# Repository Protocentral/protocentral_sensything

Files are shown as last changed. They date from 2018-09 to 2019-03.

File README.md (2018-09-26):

ProtoCentral Sensything
=======================================================

### Support us now on Crowd Supply at: https://www.crowdsupply.com/protocentral/sensything

Sensything is an ESP32-based IoT device that has multiple sensor interfaces to read from and send data from both analog and digital sensors.

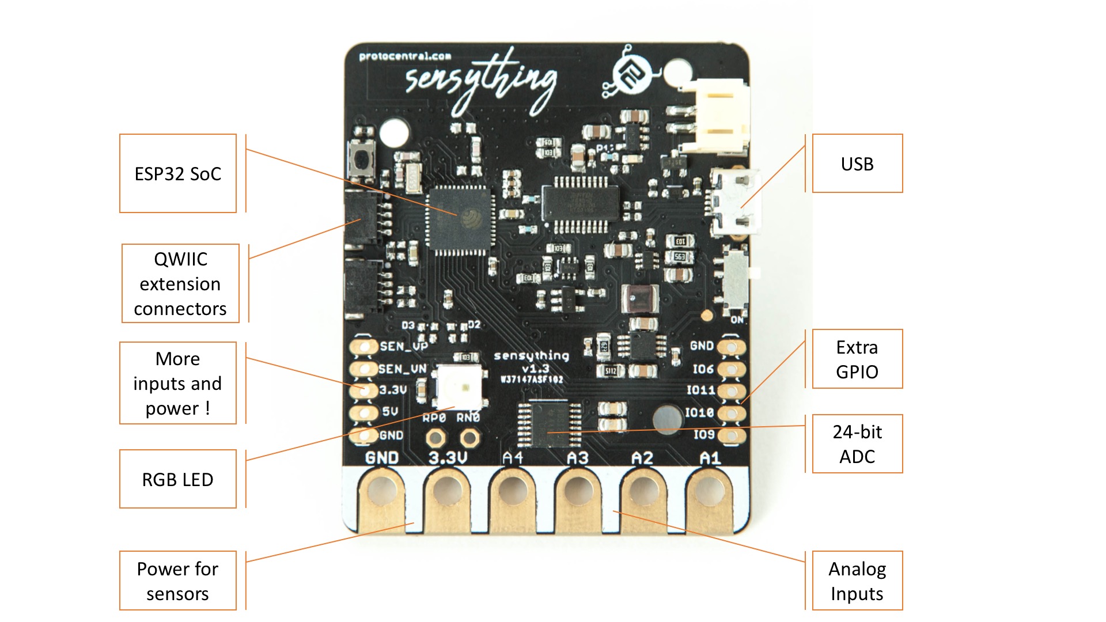
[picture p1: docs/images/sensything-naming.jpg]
HeartyPatch


## Information will be added constantly, keep checking this page for more.

License Information
===================

This product is open source! Both, our hardware and software are open source and licensed under the following licenses:

Hardware
---------

**All hardware is released under [Creative Commons Share-alike 4.0 International](http://creativecommons.org/licenses/by-sa/4.0/).**


You are free to:

* Share — copy and redistribute the material in any medium or format
* Adapt — remix, transform, and build upon the material for any purpose, even commercially.
The licensor cannot revoke these freedoms as long as you follow the license terms.

Under the following terms:

* Attribution — You must give appropriate credit, provide a link to the license, and indicate if changes were made. You may do so in any reasonable manner, but not in any way that suggests the licensor endorses you or your use.
* ShareAlike — If you remix, transform, or build upon the material, you must distribute your contributions under the same license as the original.

Software
--------

**All software is released under the MIT License(http://opensource.org/licenses/MIT).**

THE SOFTWARE IS PROVIDED "AS IS", WITHOUT WARRANTY OF ANY KIND, EXPRESS OR IMPLIED, INCLUDING BUT NOT LIMITED TO THE WARRANTIES OF MERCHANTABILITY, FITNESS FOR A PARTICULAR PURPOSE AND NONINFRINGEMENT. IN NO EVENT SHALL THE AUTHORS OR COPYRIGHT HOLDERS BE LIABLE FOR ANY CLAIM, DAMAGES OR OTHER LIABILITY, WHETHER IN AN ACTION OF CONTRACT, TORT OR OTHERWISE, ARISING FROM, OUT OF OR IN CONNECTION WITH THE SOFTWARE OR THE USE OR OTHER DEALINGS IN THE SOFTWARE.

Please check [*LICENSE.md*](LICENSE.md) for detailed license descriptions.

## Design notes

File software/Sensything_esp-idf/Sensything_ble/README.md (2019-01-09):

# Sensything 
Sensything development repo

**ads1220**

|ADS1220 Pin |Sensything Pin Connection|
|---|---|
| MISO |  19 | 
| MOSI |  23 |
| SCLK |  18 |
| DRDY |  34 |

**QWIIC**

|QWIIC Pin |QWIIC 1 Pin Connection|QWIIC 2 Pin Connection|
|---|---|---|
| SCL |  22 | 25
| SDA |  21 |26

**battery monitor**

ADC ---> 2   
 
```diff
+ Please configure sensything through makemenuconfig
```
* You can enable different channel under makemenuconfig-->sensything configuration-->adc channels
* You can also enable ble, wifi, rgb led through the same sensything configuration
* This code will work with esp-idf release 2.1 and 3.0, please select your idf version from sensything configuration-->select esp-idf version

## BLE DATA FORMAT

#1589F0 ADS1220 #1589F0 

ADS1220 data is send through a proprietary BLE service, it also has a standard [battery service](https://www.bluetooth.com/specifications/gatt/viewer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) to dispaly the battery value.

* data type : float
* service UUID : cd5c 1105 4448 7db8 ae4c d1da8cba36d0
* char UUID :    cd5c 1106 4448 7db8 ae4c d1da8cba36d0
* read voltage in float from ads1220 is multiplied by 100 and converted to int.
* 4byte int data is added to bledata packet, 

  bledatapacket[0] = (uint8_t) ads1220 data  [lsb]
  :
  bledatapacket[3] = (uint8_t) ads1220 data >> 24  [msb]
  
* Ble datapacket[0-3] = channel 1 data
* Ble datapacket[4-7] = channel 2 data
* Ble datapacket[8-11] = channel 3 data
* Ble datapacket[12-15] = channel 4 data

#1589F0 QWIIC #1589F0 

Data from QWIIC sensors is send through another proprietary service

* service UUID : cd5c 1100 4448 7db8 ae4c d1da8cba36d0
* char UUID :    cd5c 1101 4448 7db8 ae4c d1da8cba36d0

It consist of 1byte sensor address and 5 sensor data channels each of 2bytes length
The sensor data length varies based on different sensors

|sensor address |LSB data channel 1| MSB of data channel 1 | ..... |MSB of data channel 5|
|---|---:|---|---|---|
| byte 0 | byte 1 | byte 2 | ........|byte 10 |

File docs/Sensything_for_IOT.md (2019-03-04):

## Sensything as an IOT device

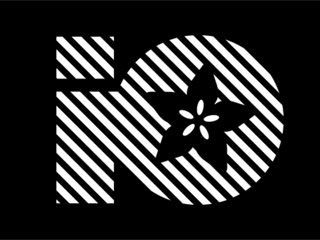
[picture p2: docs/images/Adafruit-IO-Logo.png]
Adafruit-IO-Logo


### * Overview

Sensything along with Adafruit IO is paves way to a whole new world of IOT. It is used for storing and then retrieving data but it can do a lot more than just that!

* Display your sensor (in this case gas sensor data) measuring gas density in real-time, online.
* Make your experiment internet-connected by reading sensor data
* Connect projects to web services like Twitter, RSS feeds, weather services, etc.
* Connect your project to other internet-enabled devices.

### * Sensything Wiring

You will need the following parts for this tutorial but it’s just Plug & Play with Sensything…..!

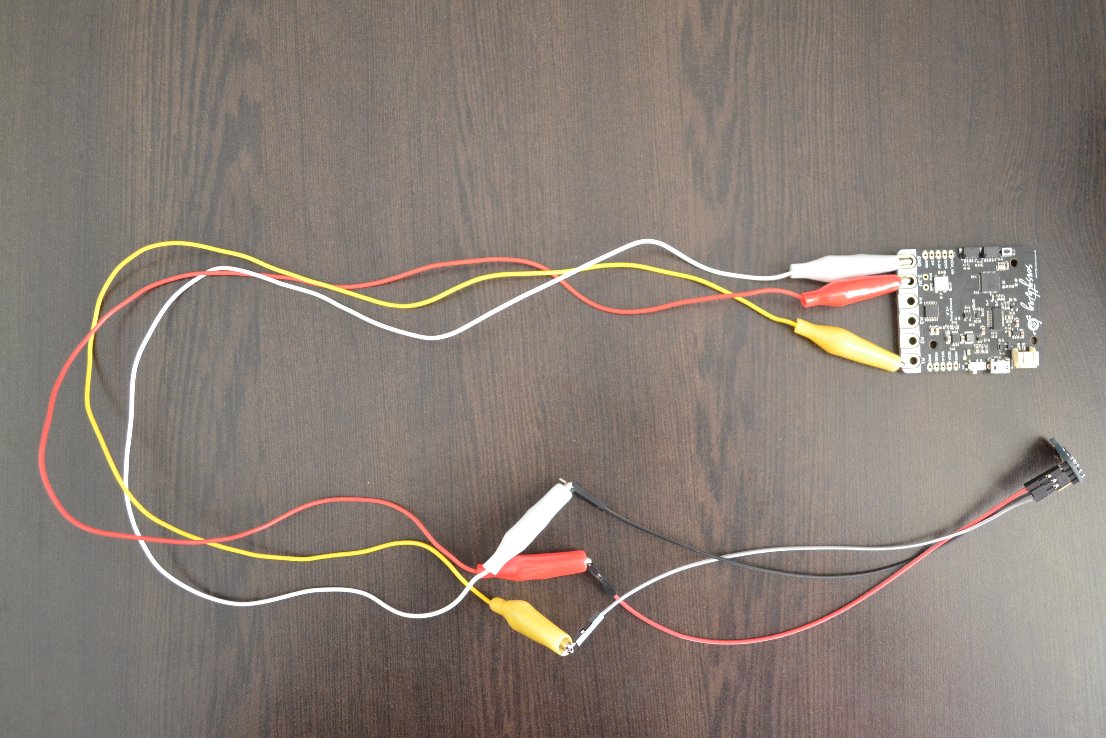
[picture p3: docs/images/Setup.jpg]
Setup


* 1x Sensything Board
* 1x [Mics5524 gas sensor](https://www.adafruit.com/product/3199)
* 3x Alligator Cables
* 3x Jumper wires

Pin connections are as follows:-

* Sensything 3V to Pin 1 of the Mics5524
* Sensything  GND to Pin 2 of the Mics5524
* Sensything  A1 to Pin 3 of the Mics5524 

### * Adafruit IO Setup

The first thing you will need to do is to log in to [Adafruit IO](https://io.adafruit.com/) and visit the Settings page. Click the VIEW AIO KEY button to retrieve your key. A window will pop up with your Adafruit IO Key. 

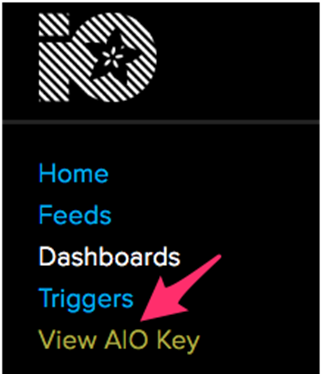
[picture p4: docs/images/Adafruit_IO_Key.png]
Adafruit IO Key
		

### * Creating the Feeds 

First, you will need to create a feed. If you need help getting started with creating feeds on Adafruit IO, check out the [Adafruit IO Feed Basics guide](https://learn.adafruit.com/adafruit-io-basics-feeds/overview).

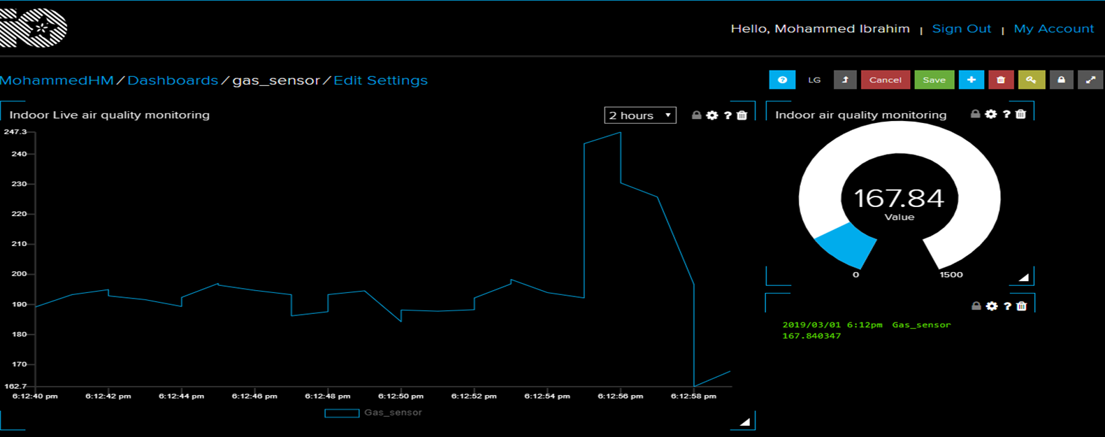
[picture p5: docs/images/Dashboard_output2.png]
Adafruit Dashboard Output2


### * Arduino Setup
 
#### * Install the Required Libraries

Initially you need to install the Adafruit IO, Adafruit MQTT, and Arduino Http Client libraries using the Arduino Library Manager. Navigate to the Manage Libraries... option in the Sketch -> Include Library menu.

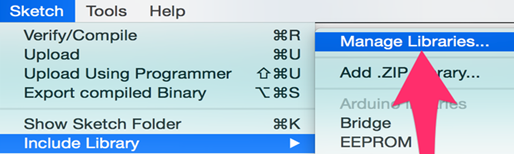
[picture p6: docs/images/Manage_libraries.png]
Manage Libraries
	

Enter Adafruit IO Arduino into the search box and click Install on the Adafruit IO Arduino library option to install version 2.7.23 or higher.

Adafruit IO Arduino	

You will also need to install the Adafruit MQTT library.

Adafruit MQTT	

#### * Arduino Network Config

To configure the network settings, click on the config.h tab in the sketch. You will need to set your Adafruit IO username in the IO_USERNAME define and your Adafruit IO key in the IO_KEY define.

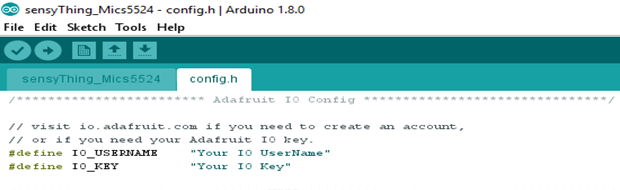
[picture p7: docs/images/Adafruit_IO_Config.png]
Adafruit IO Config


#### * WiFi Config

WiFi is enabled by default in config.h. You will only need to modify the wifi_ssid and wifi_ssid options in the config.h tab.

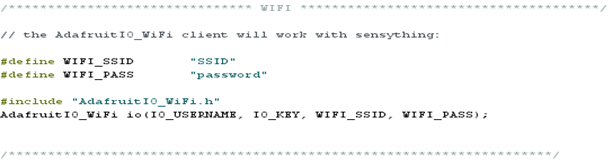
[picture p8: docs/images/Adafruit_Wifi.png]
Adafruit Wifi Config


#### * Arduino Code

The sensyThing_MICS example initializes the inbuilt  ADS1220 in your sensything, and also connects your sensything to Adafruit IO. 

```c
ADS1220.begin();
io.connect();
```
The first line of the loop function calls io.run(); this line will need to be present at the top of your loop in every sketch. It helps keep your device connected to Adafruit IO, and processes any incoming data.
The next chunk of code inside the loop checks the current MICS gas density and saves the value.
```c
io.run();
```

We then print gas density value to the Arduino Serial Monitor and save the value to the gas density feed on Adafruit IO. Upload the sketch to your board and open the Arduino Serial Monitor. Your board should now connect to Adafruit IO. Check your dashboard on Adafruit IO and you should see the line chart update with the changes in the gas sensor.
 
```c
  float Vout = (float)((bit32*VFSR*1000)/FSR);     //In  mV
  Serial.print("Gas Concentration:");
  Serial.println(Vout);
  gas_sensor->save(Vout);
```

Upload the sketch to Sensything, and open the Arduino Serial Monitor. Sensything should now connect to Adafruit IO.

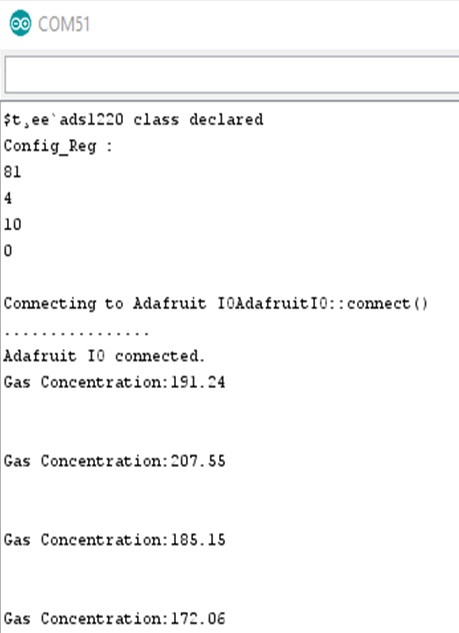
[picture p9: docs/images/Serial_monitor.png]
Arduino Serial Monitor


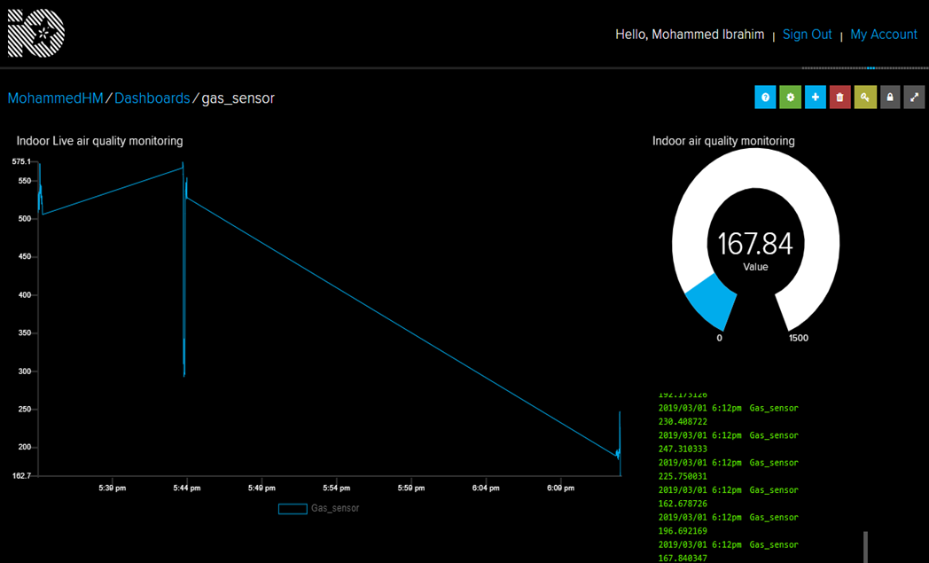
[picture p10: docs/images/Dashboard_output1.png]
Adafruit Dashboard Output1


[Download the Sensything-AdafruitIO code](https://github.com/Protocentral/protocentral_sensything/tree/master/software/)

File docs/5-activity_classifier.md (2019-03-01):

---
menu: Experiment 3 - Activity Classifier
parent: Connecting-qwiic-sensors.md
weight: 2
--- 

### Experiment 3 - Activity Classifier

#### * Introduction
Activity classification is the task of identifying a pre-defined set of physical actions using motion-sensory inputs. The activity classifier is somewhat similar to the stability classifier which it uses the on-board cortex in the sensor .to determine. 

#### * Objective
To determine what activity the IMU is doing and create a model using Sensything to classify physical activities done by users or the system.

#### * Application
The BNO080 Inertial Measurement Unit (IMU) can be used to monitor activity levels for health applications, the daily physical activity of human-beings with motion-sensory inputs.

#### * Procedure
BNO080 sensor is used as an activity classifier, the sensor data is combined and drift corrected into meaningful, accurate IMU information. It is perfect for any project that needs to sense orientation or motion. The sensor can be interfaced with Sensything using the Qwiic connector, which makes it very quick to just plug in to read data from sensor. Once you upload the code given below using the esp-idf to your Sensything,you will get the activity classification based on your input or movement in the motion-sensory input. Hence the data will be printed on your serial monitor. 

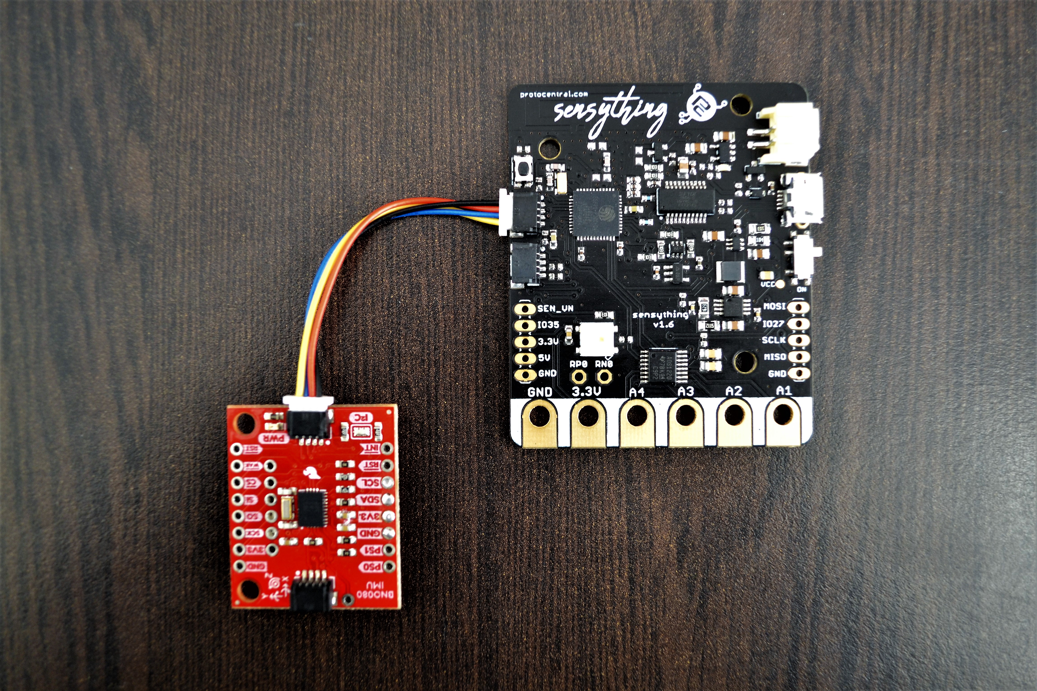
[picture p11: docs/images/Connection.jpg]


#### * Excerpts from the code:

```c
uint32_t enableActivities = 0x1F; //Enable all 9 possible activities including Unknown
_activityConfidences = activity;
    
activity_data.activity_values = activityClassifier;
const uint8_t mostLikelyActivity = activity_data.activity_values;
printActivityName(mostLikelyActivity);             

```

#### * Pin mapping and connection instructions:

<style type="text/css">
.tg  {border-collapse:collapse;border-spacing:0;}
.tg td{font-family:Arial, sans-serif;font-size:14px;padding:10px 5px;border-style:solid;border-width:1px;overflow:hidden;word-break:normal;border-color:black;}
.tg th{font-family:Arial, sans-serif;font-size:14px;font-weight:normal;padding:10px 5px;border-style:solid;border-width:1px;overflow:hidden;word-break:normal;border-color:black;}
.tg .tg-baqh{text-align:center;vertical-align:top}
.tg .tg-s268{text-align:left}
.tg .tg-nk0m{font-size:16px;font-family:Tahoma, Geneva, sans-serif !important;;text-align:left;vertical-align:top}
</style>
<table class="tg">
  <tr>
    <th class="tg-s268"><span style="font-weight:600">Sensything pin label</span></th>
    <th class="tg-nk0m"><span style="font-weight:600">BNO080 Sensor</span></th>
    <th class="tg-nk0m"><span style="font-weight:600">Colour</span></th>
  </tr>
  <tr>
    <td class="tg-baqh">SDA</td>
    <td class="tg-baqh">Serial Data</td>
    <td class="tg-baqh">Blue</td>
  </tr>
  <tr>
    <td class="tg-baqh">SCL</td>
    <td class="tg-baqh">Serial Clock</td>
    <td class="tg-baqh">Yellow</td>
  </tr>
  <tr>
    <td class="tg-baqh">3V3</td>
    <td class="tg-baqh">3v3</td>
    <td class="tg-baqh">Red</td>
  </tr>
  <tr>
    <td class="tg-baqh">GND</td>
    <td class="tg-baqh">GND</td>
    <td class="tg-baqh">Black</td>
  </tr>
</table> 

&ensp;

<style type="text/css">
.tg  {border-collapse:collapse;border-spacing:0;}
.tg td{font-family:Arial, sans-serif;font-size:14px;padding:10px 5px;border-style:solid;border-width:1px;overflow:hidden;word-break:normal;border-color:black;}
.tg th{font-family:Arial, sans-serif;font-size:14px;font-weight:normal;padding:10px 5px;border-style:solid;border-width:1px;overflow:hidden;word-break:normal;border-color:black;}
.tg .tg-u8t5{font-family:Tahoma, Geneva, sans-serif !important;;text-align:center}
.tg .tg-0lax{text-align:left;vertical-align:top}
</style>
<table class="tg">
  <tr>
    <th class="tg-u8t5"><span style="font-weight:bold">Connection Instructions</span></th>
  </tr>
  <tr>
    <td class="tg-0lax">- It is a Quick and Qwiic connection with sensything</td>
  </tr>
  <tr>
    <td class="tg-0lax">- Plug the Qwiic Connector for interface between sensor and sensything.</td>
  </tr>
     <tr>
    <td class="tg-0lax">- Upload the code using esp-idf toolchain to your sensyhting board.</td>
  </tr>
  <tr>
    <td class="tg-0lax">- Get the activity classifier of defined sensor - inputs based on sensor movement. </td>
  </tr>
</table>

[Download the bno080 Activity Classifier Sensor code]()

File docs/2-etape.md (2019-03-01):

---
menu: Experiment 2 - Water level sensor
parent: connecting-sensors.md
weight: 1
---

### Experiment 2 - Water level check

#### * Objective
To determine the level of any liquid.

#### * Application
It can determine the continuous liquid level monitoring of water, non-corrosive water or dry fluids.

#### * Procedure
The eTape Liquid Level Sensor is a solid-state sensor with a resistive output that varies with the level of the fluid. It does away with clunky mechanical floats, and easily interfaces with electronic control systems. The eTape sensor's envelope is compressed by the hydrostatic pressure of the fluid in which it is immersed. This results in a change in resistance that corresponds to the distance from the top of the sensor to the surface of the fluid. The sensor's resistive output is inversely proportional to the height of the liquid: the lower the liquid level, the higher the output resistance; the higher the liquid level, the lower the output resistance.

Here we can calculate the output resistance from converting the ADC data in sensything. Below we measure the e-tape liquid level sensor output resistance.

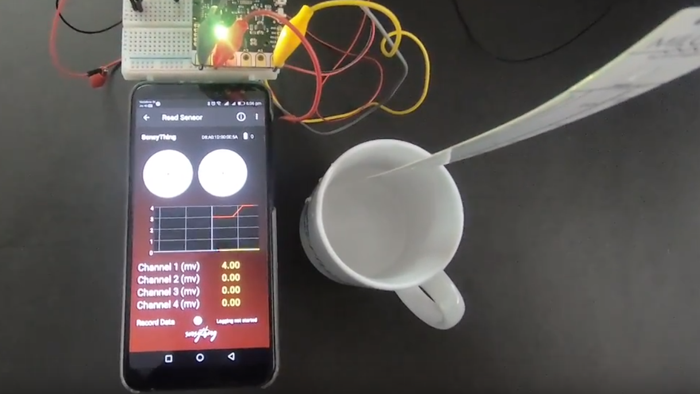
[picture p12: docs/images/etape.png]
Etape Sensor


#### * Excerpts from the code:

```c
float Vout = (float)((bit32*VFSR*1000)/FSR);     //In  mV
// convert the value to resistance
 float reading = (1023 / Vout)  - 1;
  reading = 560 / reading;
  Serial.print("Sensor resistance ");
  Serial.println(reading);
```

#### * Pin mapping and connection instructions:

<style type="text/css">
.tg  {border-collapse:collapse;border-spacing:0;}
.tg td{font-family:Arial, sans-serif;font-size:14px;padding:10px 5px;border-style:solid;border-width:1px;overflow:hidden;word-break:normal;border-color:black;}
.tg th{font-family:Arial, sans-serif;font-size:14px;font-weight:normal;padding:10px 5px;border-style:solid;border-width:1px;overflow:hidden;word-break:normal;border-color:black;}
.tg .tg-baqh{text-align:center;vertical-align:top}
.tg .tg-s268{text-align:left}
.tg .tg-nk0m{font-size:16px;font-family:Tahoma, Geneva, sans-serif !important;;text-align:left;vertical-align:top}
</style>
<table class="tg">
  <tr>
    <th class="tg-s268"><span style="font-weight:bold">Sensything pin label</span></th>
    <th class="tg-nk0m"><span style="font-weight:bold">etape liquid Sensor</span></th>
  </tr>
  <tr>
    <td class="tg-baqh">A1</td>
    <td class="tg-baqh">Pin 3</td>
  </tr>
  <tr>
    <td class="tg-baqh">3V3</td>
    <td class="tg-baqh">Pin 2</td>
  </tr>
  <tr>
    <td class="tg-baqh">GND</td>
    <td class="tg-baqh">Pin 3-Across resistor</td>
  </tr>
</table>

&ensp;

<style type="text/css">
.tg  {border-collapse:collapse;border-spacing:0;}
.tg td{font-family:Arial, sans-serif;font-size:14px;padding:10px 5px;border-style:solid;border-width:1px;overflow:hidden;word-break:normal;border-color:black;}
.tg th{font-family:Arial, sans-serif;font-size:14px;font-weight:normal;padding:10px 5px;border-style:solid;border-width:1px;overflow:hidden;word-break:normal;border-color:black;}
.tg .tg-s6z2{text-align:center}
.tg .tg-0lax{text-align:left;vertical-align:top}
</style>
<table class="tg">
  <tr>
    <th class="tg-s6z2"><span style="font-weight:bold">Connection Instructions</span></th>
  </tr>
  <tr>
    <td class="tg-0lax">- Place the etape liquid level sensor to any of the analog pins A1, A2, A3 and A4.</td>
  </tr>
  <tr>
    <td class="tg-0lax">- Here we are using A1.</td>
  </tr>
  <tr>
    <td class="tg-0lax">- Connect pin2 of etape with Vcc in Sensything.</td>
  </tr>
  <tr>
    <td class="tg-0lax">- Connect pin3 of sensor with Analog1 in Sensything.</td>
  </tr>
  <tr>
    <td class="tg-0lax">- Using a breadboard connect a resistor between pin3 in sensor and GND in breadboard.</td>
  </tr>
  <tr>
    <td class="tg-0lax">- Connect GND across the resistor with the GND pin in Sensything.</td>
  </tr>
</table>  | 

[Download the etape Liquid level code](https://github.com/Protocentral/protocentral_sensything/tree/master/software/Sensything_Arduino/experiments/Analog_Sensors/examples/sensyThing_etape)

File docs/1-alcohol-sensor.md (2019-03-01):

---
menu: Experiment 1 - Alcohol Sensor
parent: connecting-sensors.md
weight: 0
---
### Experiment 1 - Alcohol detector

#### * Objective
To determine the level of Alcohol in any liquid.

#### * Application
This sensor has a good level of sensitivity it can be used as a portable alcohol detector.

#### * Procedure
MQ303A is a semiconductor sensor for Alcohol detection. It has very good sensitivity and fast response to alcohol, suitable for portable alcohol detector just plugging with sensything. Below you find the conversion of ADC data to the content of alcohol to be detected with milligram per litre. When the content of alcohol is more than 0.8 it detects the presence of alcohol.

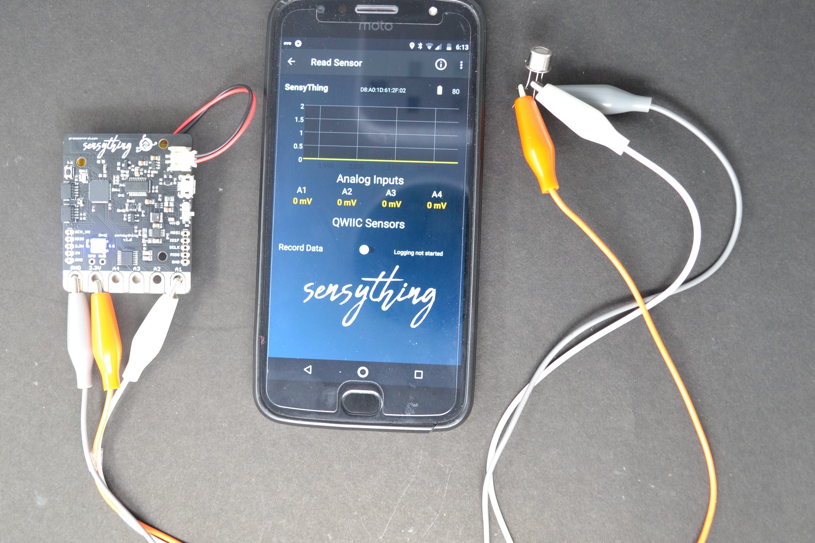
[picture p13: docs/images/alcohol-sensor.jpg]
Alcohol Sensor


#### * Excerpts from the code:

```c
float adc_data = (float)((bit32*VFSR*1000)/FSR);     //In  mV
float v = (adc_data/10) * (5.0/1024.0);
float mgL = 0.67 * v;

if(mgL > 0.8)
{   
	Serial.print("mg/L : %f \n");
	Serial.print(" Alcohol Detected");
	Serial.println(mgL);
 }
else
{    
	Serial.print("mg/L : %f \n");
	Serial.print(" Alcohol Not Detected");
	Serial.println(mgL);
}  
```

#### * Pin mapping and connection instructions:

<style type="text/css">
.tg  {border-collapse:collapse;border-spacing:0;}
.tg td{font-family:Arial, sans-serif;font-size:14px;padding:10px 5px;border-style:solid;border-width:1px;overflow:hidden;word-break:normal;border-color:black;}
.tg th{font-family:Arial, sans-serif;font-size:14px;font-weight:normal;padding:10px 5px;border-style:solid;border-width:1px;overflow:hidden;word-break:normal;border-color:black;}
.tg .tg-baqh{text-align:center;vertical-align:top}
.tg .tg-s268{text-align:left}
.tg .tg-nk0m{font-size:16px;font-family:Tahoma, Geneva, sans-serif !important;;text-align:left;vertical-align:top}
</style>
<table class="tg">
  <tr>
    <th class="tg-s268"><span style="font-weight:600">Sensything pin label</span></th>
    <th class="tg-nk0m"><span style="font-weight:600">Alcohol Sensor</span></th>
  </tr>
  <tr>
    <td class="tg-baqh">A1</td>
    <td class="tg-baqh">Analog out</td>
  </tr>
  <tr>
    <td class="tg-baqh">3V3</td>
    <td class="tg-baqh">VCC</td>
  </tr>
  <tr>
    <td class="tg-baqh">GND</td>
    <td class="tg-baqh">GND</td>
  </tr>
</table> 

&ensp;

<style type="text/css">
.tg  {border-collapse:collapse;border-spacing:0;}
.tg td{font-family:Arial, sans-serif;font-size:14px;padding:10px 5px;border-style:solid;border-width:1px;overflow:hidden;word-break:normal;border-color:black;}
.tg th{font-family:Arial, sans-serif;font-size:14px;font-weight:normal;padding:10px 5px;border-style:solid;border-width:1px;overflow:hidden;word-break:normal;border-color:black;}
.tg .tg-u8t5{font-family:Tahoma, Geneva, sans-serif !important;;text-align:center}
.tg .tg-0lax{text-align:left;vertical-align:top}
</style>
<table class="tg">
  <tr>
    <th class="tg-u8t5"><span style="font-weight:bold">Connection Instructions</span></th>
  </tr>
  <tr>
    <td class="tg-0lax">- Place the alcohol sensor to any of the analog pins A1, A2, A3 and A4.</td>
  </tr>
  <tr>
    <td class="tg-0lax">- Here we are using A1.</td>
  </tr>
  <tr>
    <td class="tg-0lax">- Connect VCC of MQ303A with VCC in Sensything.</td>
  </tr>
  <tr>
    <td class="tg-0lax">- Connect GND of sensor with GND in Sensything.</td>
  </tr>
  <tr>
    <td class="tg-0lax">- Connect output of sensor with Analog 1 in Sensything.</td>
  </tr>
</table>

[Download the Alcohol Sensor code](https://github.com/Protocentral/protocentral_sensything/tree/master/software/Sensything_Arduino/experiments/Analog_Sensors/examples/sensyThing_mq303A)

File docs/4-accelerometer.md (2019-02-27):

---
menu: Experiment 1 - Measuring Acceleration
parent: Connecting-qwiic-sensors.md
weight: 0
---

### Experiment 1 - Measuring Acceleration

#### * Introduction
Accelerometer sensor(BNO080) with sensything is used for measuring acceleration, which is the rate of change of the velocity of an object. This measure in meters per second squared (m/s2) or in G-forces (g). A single G-force for us here on planet Earth is equivalent to 9.8 m/s2, but this does vary slightly with elevation (and will be a different value on different planets due to variations in gravitational pull). 

#### * Objective
To determine the sensing vibrations using sensything in systems or for orientation applications.

#### * Application
The accelerometer sensor(BNO080) can be used for service robots such as cleaners that employ Simultaneous Localization And Mapping (SLAM) or other ‘intelligent’ navigation solutions and automated projects.

#### * Procedure
BNO080 accelerometer sensor is used for measuring acceleration. It integrates a triaxial 12-bit accelerometer with a range of ±8g, the sensor can be interfaced with sensything using Qwiic connector very quick or just plug to read data from sensor. Once you upload the code given below using Arduino IDE to your sensything you will can read the x,y and z axes data printed in your serial monitor. Also, be sure to check out the labeling on the front of the board that indicates the orientation of the positive X, Y, and Z axes so you know which way your data is pointing.



#### * Excerpts from the code:

```c
float x = myIMU.getAccelX();         // Accelerometer reading of X
float y = myIMU.getAccelY();         // Accelerometer reading of Y
float z = myIMU.getAccelZ();         // Accelerometer reading of Z
```

#### * Pin mapping and connection instructions:

<style type="text/css">
.tg  {border-collapse:collapse;border-spacing:0;}
.tg td{font-family:Arial, sans-serif;font-size:14px;padding:10px 5px;border-style:solid;border-width:1px;overflow:hidden;word-break:normal;border-color:black;}
.tg th{font-family:Arial, sans-serif;font-size:14px;font-weight:normal;padding:10px 5px;border-style:solid;border-width:1px;overflow:hidden;word-break:normal;border-color:black;}
.tg .tg-baqh{text-align:center;vertical-align:top}
.tg .tg-s268{text-align:left}
.tg .tg-nk0m{font-size:16px;font-family:Tahoma, Geneva, sans-serif !important;;text-align:left;vertical-align:top}
</style>
<table class="tg">
  <tr>
    <th class="tg-s268"><span style="font-weight:600">Sensything pin label</span></th>
    <th class="tg-nk0m"><span style="font-weight:600">Alcohol Sensor</span></th>
    <th class="tg-nk0m"><span style="font-weight:600">Colour</span></th>
  </tr>
  <tr>
    <td class="tg-baqh">SDA</td>
    <td class="tg-baqh">Serial Data</td>
    <td class="tg-baqh">Blue</td>
  </tr>
  <tr>
    <td class="tg-baqh">SCL</td>
    <td class="tg-baqh">Serial Clock</td>
    <td class="tg-baqh">Yellow</td>
  </tr>
  <tr>
    <td class="tg-baqh">3V3</td>
    <td class="tg-baqh">3v3</td>
    <td class="tg-baqh">Red</td>
  </tr>
  <tr>
    <td class="tg-baqh">GND</td>
    <td class="tg-baqh">GND</td>
    <td class="tg-baqh">Black</td>
  </tr>
</table> 

&ensp;

<style type="text/css">
.tg  {border-collapse:collapse;border-spacing:0;}
.tg td{font-family:Arial, sans-serif;font-size:14px;padding:10px 5px;border-style:solid;border-width:1px;overflow:hidden;word-break:normal;border-color:black;}
.tg th{font-family:Arial, sans-serif;font-size:14px;font-weight:normal;padding:10px 5px;border-style:solid;border-width:1px;overflow:hidden;word-break:normal;border-color:black;}
.tg .tg-u8t5{font-family:Tahoma, Geneva, sans-serif !important;;text-align:center}
.tg .tg-0lax{text-align:left;vertical-align:top}
</style>
<table class="tg">
  <tr>
    <th class="tg-u8t5"><span style="font-weight:bold">Connection Instructions</span></th>
  </tr>
  <tr>
    <td class="tg-0lax">- It is a Quick and Qwiic connection with sensything</td>
  </tr>
  <tr>
    <td class="tg-0lax">- Plug the Qwiic Connector for interface between sensor and sensything.</td>
  </tr>
     <tr>
    <td class="tg-0lax">- Upload the code using Arduino IDE and read accelerometer readings.</td>
  </tr>
</table>

[Download the Accelerometer Sensor code](https://github.com/Protocentral/protocentral_sensything/tree/master/software/Sensything_Arduino/experiments/Qwiic/BNO080)

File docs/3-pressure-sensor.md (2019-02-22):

---
menu: Experiment 2 - Pressure Sensor
parent: Connecting-qwiic-sensors.md
weight: 1
---

### Experiment 2 - Barometric pressure sensor

#### * Objective

To determine the Barometric pressure.

#### * Application

BMP180 barometric pressure sensor can be used to predict the weather, detect altitude, and measure vertical velocity.

#### * Procedure
This sensor is one of the low-cost solutions for sensing applications related to barometric pressure and temperature. The BMP180 can communicate directly with a microcontroller in the device through I2C or SPI as a variant. The applications for this sensor is navigation, GPS positioning as well as a tracker for hikers. We have enabled Qwiic connection using the channels.

BMP180 Sensor

#### * Excerpts from the code:
```c
baseline = getPressure();
Serial.print("baseline pressure: ");
Serial.print(baseline);
```
```c
double a,P;

P = getPressure();             // Get a new pressure reading:
a = pressure.altitude(P,baseline); // Show the relative altitude difference between the new reading and the baseline reading

char status;
double T,P;

status = pressure.startTemperature();
status = pressure.getTemperature(T);

status = pressure.startPressure();
status = pressure.getPressure(P,T);
```

[Download the full code here](https://github.com/Protocentral/protocentral_sensything/tree/master/software/Sensything_Arduino/experiments/Qwiic/examples/sensything_bmp180)

#### * Pin mapping and connection instructions:

<style type="text/css">
.tg  {border-collapse:collapse;border-spacing:0;}
.tg td{font-family:Arial, sans-serif;font-size:14px;padding:10px 5px;border-style:solid;border-width:1px;overflow:hidden;word-break:normal;border-color:black;}
.tg th{font-family:Arial, sans-serif;font-size:14px;font-weight:normal;padding:10px 5px;border-style:solid;border-width:1px;overflow:hidden;word-break:normal;border-color:black;}
.tg .tg-baqh{text-align:center;vertical-align:top}
.tg .tg-s268{text-align:left}
.tg .tg-nk0m{font-size:16px;font-family:Tahoma, Geneva, sans-serif !important;;text-align:left;vertical-align:top}
</style>
<table class="tg">
  <tr>
    <th class="tg-s268"><span style="font-weight:600">Sensything pin label</span></th>
    <th class="tg-nk0m"><span style="font-weight:bold">BMP180 Sensor</span></th>
  </tr>
  <tr>
    <td class="tg-baqh">sda</td>
    <td class="tg-baqh">sda</td>
  </tr>
  <tr>
    <td class="tg-baqh">scl</td>
    <td class="tg-baqh">scl</td>
  </tr>
  <tr>
    <td class="tg-baqh">3V3</td>
    <td class="tg-baqh">Vcc</td>
  </tr>
  <tr>
    <td class="tg-baqh">GND</td>
    <td class="tg-baqh">GND</td>
  </tr>
</table>

&ensp;

<style type="text/css">
.tg  {border-collapse:collapse;border-spacing:0;}
.tg td{font-family:Arial, sans-serif;font-size:14px;padding:10px 5px;border-style:solid;border-width:1px;overflow:hidden;word-break:normal;border-color:black;}
.tg th{font-family:Arial, sans-serif;font-size:14px;font-weight:normal;padding:10px 5px;border-style:solid;border-width:1px;overflow:hidden;word-break:normal;border-color:black;}
.tg .tg-s6z2{text-align:center}
.tg .tg-0lax{text-align:left;vertical-align:top}
</style>
<table class="tg">
  <tr>
    <th class="tg-s6z2"><span style="font-weight:bold">Connection Instructions</span></th>
  </tr>
  <tr>
    <td class="tg-0lax">- Connect the Qwiic BMP180 directly into the sensything Qwiic-1 or Qwiic-2 port</td>
  </tr>
</table>

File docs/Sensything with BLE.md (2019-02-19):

---
menu: Sensything with BLE
parent: getting-started.md
weight: 4
---
### Sensything with BLE

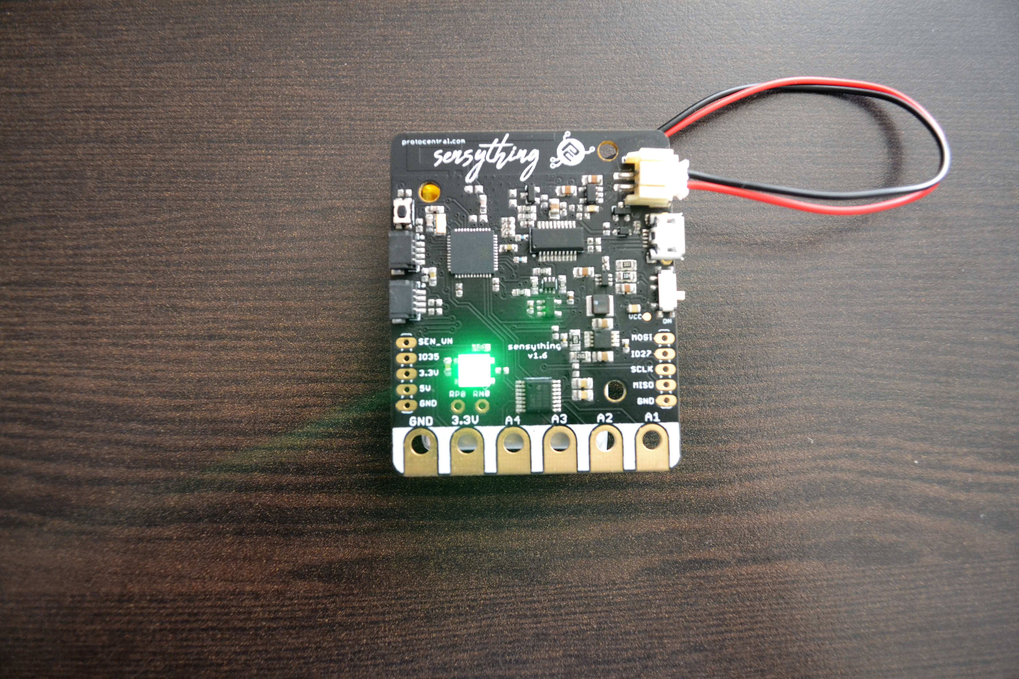
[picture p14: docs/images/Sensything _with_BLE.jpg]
 

The Sensything board comes with the feature -

**Bluetooth 4.2 / Bluetooth Low Energy (BLE) compatible**

In order for the device to connect with the Sensything Application, the Arduino code must be set up.

#### How to set up the BLE function?

The Sensything  Application has been designed to simplify the detection of sensor values. With the inbuilt ADC (ADS1220) the precise values can be detected and displayed. Few simple steps:

**Step 1: Writing the code**
Using the Arduino IDE, write the code for the sensor of your choice and monitor the live values in the sensything mobile application. Refer to the above mentioned code for sensything with ble to get tips on writing/uploading the code.

You need to define a UUID for the Service and Characteristic.
```c
#define SERVICE_UUID        "cd5c1105-4448-7db8-ae4c-d1da8cba36d0"
#define CHARACTERISTIC_UUID "cd5c1106-4448-7db8-ae4c-d1da8cba36d0"
```
Then, you create a BLE device called “Sensything”. You can change this name to whatever you like.Create the BLE Device
```c
BLEDevice::init("Sensything");
```
In the following line, you need to set the Sensything as a server.
```c
BLEServer *pServer = BLEDevice::createServer();
```
After that, you create a service for the BLE server with the UUID defined earlier.

 ```c
 BLEService *pService = pServer->createService(SERVICE_UUID);
 ```
 
Then, you set the characteristic for that service. As you can see, you also use the UUID defined earlier, and you need to pass as arguments the characteristic’s properties. In this case, it’s: READ and WRITE.

Now you can get the adc data from sensything 4 different channels and send the data value through ble packet format and display the live values in the sensything mobile application.

```c
adc_data=pc_ads1220.Read_SingleShot_SingleEnded_WaitForData(MUX_SE_CH0); // Getting analog channel 1 value
float vout = convertToMilliV(adc_data);

int32_t ble = (int32_t) (vout * 100);
ads1220_data[0]= (uint8_t) ble;
ads1220_data[1]= (uint8_t) (ble >> 8);
ads1220_data[2]= (uint8_t) (ble >> 16);
ads1220_data[3]= (uint8_t) (ble >> 24);
```
    
After creating the characteristic, you can set the ads1220 value with the setValue() method.   

```c
// notify changed value
if (deviceConnected ) {
pCharacteristic->setValue(ads1220_data, 16);
pCharacteristic->notify(); 
}
```
    
Now that Arduino IDE is all set up, download the sensything ble code provided in the github and open the sketch provided for this tutorial (link below).This example works with the sensything application on your phone. Make sure to install the app to follow along with this example.

**Step 2: Connecting the sensor**
The next step is to connect the sensors to the Sensything board. Sensors that can be used along with sensything are both Analog and Qwiic. Hence you can choose sensor of your choice based on your application and can get the sensor values through BLE.You can refer the experiments provided as examples.

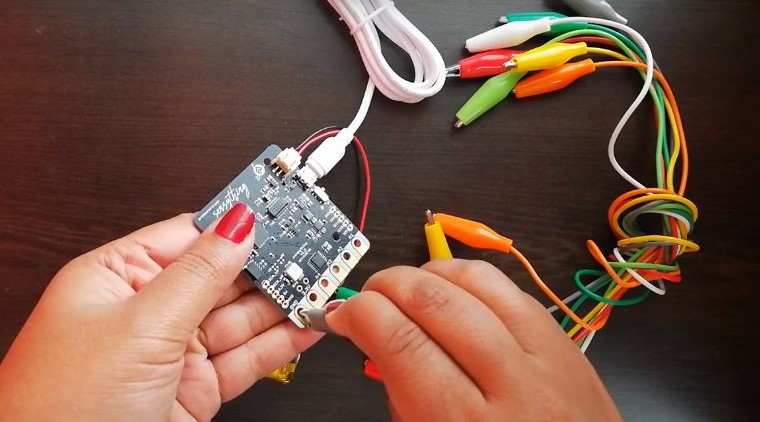
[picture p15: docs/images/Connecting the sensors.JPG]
 
 
**Step 3: Uploading the code** 
Connect the Sensything board to your system using a USB cable. Once the code is selected in Arduino IDE you should select Tools / Board. Choose "ESP32 Dev Module" for sensything board. Also go ahead and choose the correct COM port after connecting the board to your computer then upload the code to your sensything board.

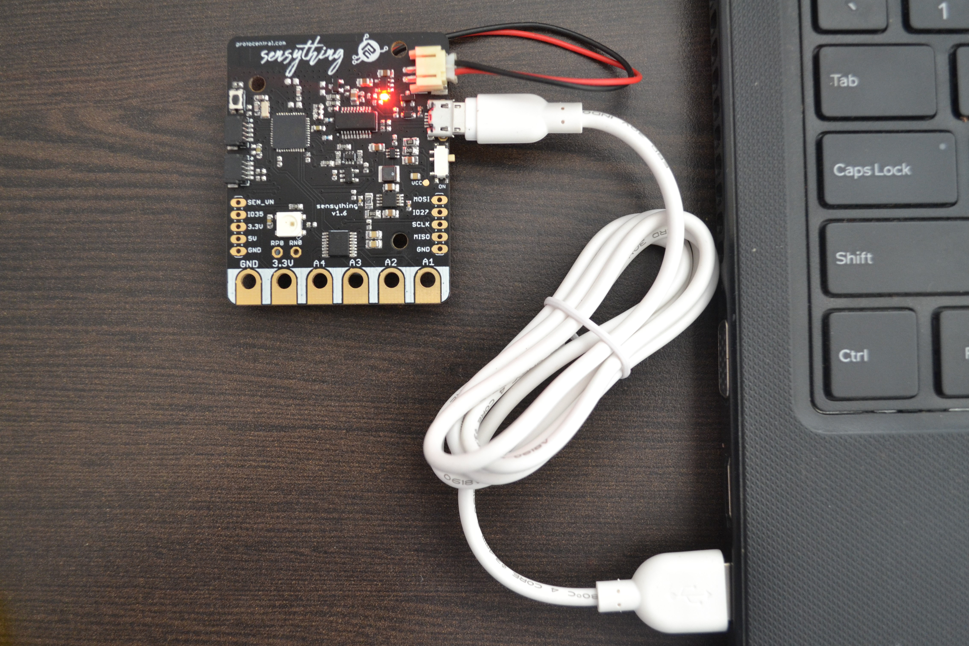
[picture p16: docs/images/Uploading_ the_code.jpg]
 
 
**Step 4: Using the Sensything Application**
You can download the sensything android application from android playstore, and once you open the application and connect to the BLE device(Sensything) you can see the live analog channel/sensor values in the sensything mobile application.

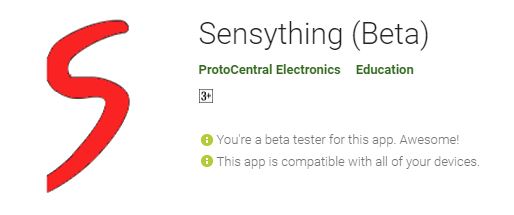
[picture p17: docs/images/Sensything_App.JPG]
 

Kindly refer to the Introduction video on how to download the Application and how to [connect](http://sensything.protocentral.com/#making-the-connections)

**Step 5: Reading the sensor values**
The sensor values are displayed in sensything mobile application and later the data can be logged on to the device.

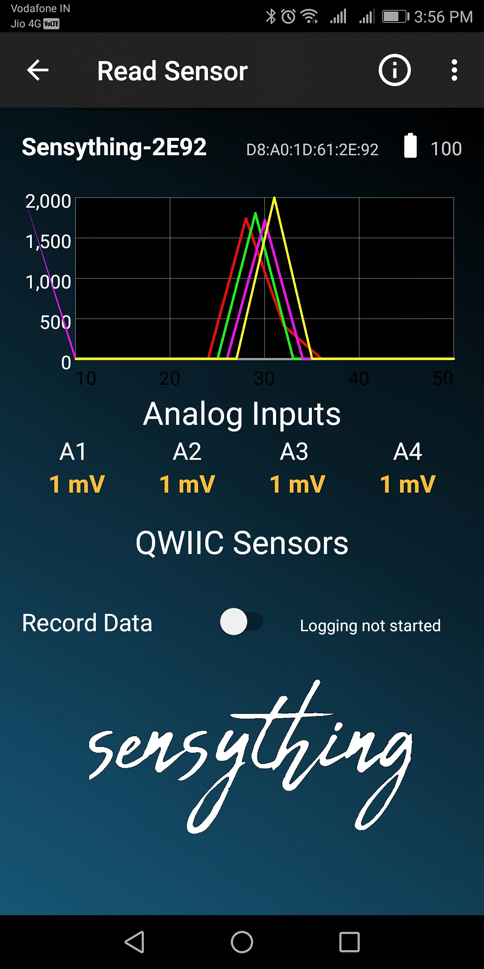
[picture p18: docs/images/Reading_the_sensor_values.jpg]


Kindly refer to the Application section on the [main page](http://sensything.protocentral.com/#understanding-the-sensything-application)

[Download the BLE code](https://github.com/Protocentral/protocentral_sensything/tree/master/software/Sensything_Arduino/Sensything_ble)

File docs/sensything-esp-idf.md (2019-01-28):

---
menu: Using with ESP IDF
parent: getting-started.md
weight: 2
---

### Using with ESP IDF

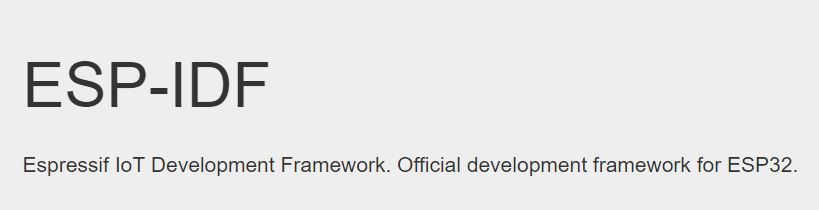
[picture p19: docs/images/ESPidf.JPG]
ESPidf


If you would like to take things up a notch, then we would suggest you program Sensything using the ESP IDF. This section is intended to help users set up the software environment of applications using Espressif ESP32. Through a simple step-by-step process to illustrate how to use ESP-IDF(Espressif IoT Development Framework).

#### What You Need?

To develop applications for ESP32 you need:
* PC loaded with either Windows, Linux or Mac operating system
* Toolchain to build the Application for ESP32
* ESP-IDF that essentially contains API for ESP32 and scripts to operate the Toolchain
* A text editor to write programs (Projects) in C

#### Preparation for development

There are three simple steps in the process of development:

* **Setup of Toolchain**
* **Getting of ESP-IDF from GitHub**
* **Installation and configuration**

**Step 1: Setting up the toolchain**

Windows don’t have a built-in “make” environment, so as well as installing the toolchain you will need a GNU-compatible environment. We can use the MSYS2 environment to provide this environment. The quick setup is to download the Windows all-in-one toolchain & MSYS2 zip file from dl.espressif.com: [Toolchain Setup- Windows](https://dl.espressif.com/dl/esp32_win32_msys2_environment_and_toolchain-20180110.zip)

The quick setup is to download the linux all-in-one toolchain from Espressif website:[Toolchain Setup 64-bit Linux](https://dl.espressif.com/dl/xtensa-esp32-elf-linux64-1.22.0-80-g6c4433a-5.2.0.tar.gz) and [Toolchain Setup 32-bit Linux](https://dl.espressif.com/dl/xtensa-esp32-elf-linux32-1.22.0-80-g6c4433a-5.2.0.tar.gz) 

The quick setup is to download the ESP32 toolchain for macOS all-in-one toolchain from Espressif website:[Toolchain Setup macOS](https://dl.espressif.com/dl/xtensa-esp32-elf-osx-1.22.0-80-g6c4433a-5.2.0.tar.gz) 

**Step 2: Getting ESP-IDF**

Besides the toolchain (that contains programs to compile and build the application), you also need ESP32 specific API / libraries. They are provided by Espressif in [ESP-IDF repository](https://www.google.com/url?q=https://docs.espressif.com/projects/esp-idf/en/latest/get-started/index.html). To get it, open terminal, navigate to the directory you want to put ESP-IDF and clone it from espressif repository in github.

**Step 3: Setting up**

To set up the software environment and get esp-idf to follow the instructions given in the link below for [Windows](https://docs.espressif.com/projects/esp-idf/en/latest/get-started/windows-setup.html), [Linux](https://docs.espressif.com/projects/esp-idf/en/latest/get-started/linux-setup.html), [Mac OS](https://docs.espressif.com/projects/esp-idf/en/latest/get-started/macos-setup.html)

To showcase how to program the Sensything board with ESP idf we have an example illustrated below:

**Experiment 1 - Gas Leakage detector**

#### * Objective

To determine the gas leakage detection (home and industry)

##### * Application

Since this sensor has a high sensitivity and fast response time, it can be used as a portable gas and smoke detector suitable for detecting H2, LPG, CH4, CO, Alcohol, Smoke or Propane.

##### * Procedure

MQ2 is a semiconductor sensor for Gas Detection. When we apply a bias to the sensor it takes some “burn-in time” that is for to sensor getting warm, after that the electrochemical sensor detects specific gas and varies the current flow through the sensor. Hence we get analog output ranges depends on Gas concentration. It has very high sensitivity and fast response time, The voltage measured from ads1220 in Sensything and converted to the sensor voltage and gas concentration is calculated. The concentration of gas is sent through BLE and displayed in the Sensything mobile application.

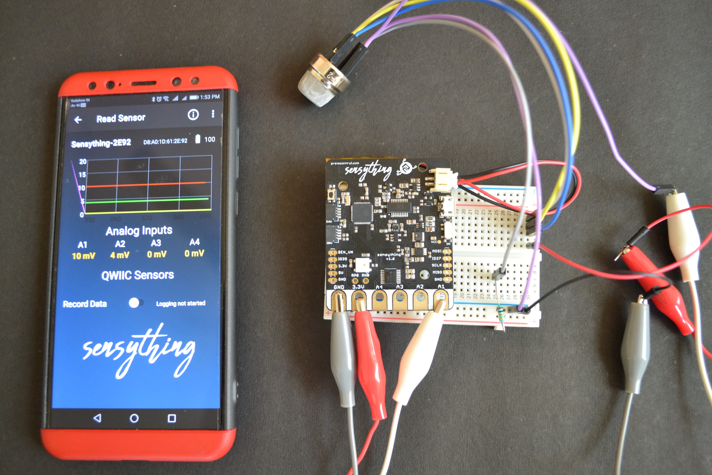
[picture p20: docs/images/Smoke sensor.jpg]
Smoke sensor


#### * Pin mapping and connection instructions:

<style type="text/css">
.tg  {border-collapse:collapse;border-spacing:0;}
.tg td{font-family:Arial, sans-serif;font-size:14px;padding:10px 5px;border-style:solid;border-width:1px;overflow:hidden;word-break:normal;border-color:black;}
.tg th{font-family:Arial, sans-serif;font-size:14px;font-weight:normal;padding:10px 5px;border-style:solid;border-width:1px;overflow:hidden;word-break:normal;border-color:black;}
.tg .tg-c3ow{border-color:inherit;text-align:center;vertical-align:top}
.tg .tg-uys7{border-color:inherit;text-align:center}
.tg .tg-xldj{border-color:inherit;text-align:left}
</style>
<table class="tg">
  <tr>
    <th class="tg-xldj"><span style="font-weight:600">Sensything pin label</span></th>
    <th class="tg-uys7"><span style="font-weight:600">MQ2 Gas Sensor</span></th>
  </tr>
  <tr>
    <td class="tg-uys7">3V3</td>
    <td class="tg-uys7">A</td>
  </tr>
  <tr>
    <td class="tg-c3ow">3V3</td>
    <td class="tg-c3ow">H</td>
  </tr>
  <tr>
    <td class="tg-c3ow">3V3</td>
    <td class="tg-c3ow">A1</td>
  </tr>
  <tr>
    <td class="tg-c3ow">A1</td>
    <td class="tg-c3ow">B</td>
  </tr>
  <tr>
    <td class="tg-c3ow">GND</td>
    <td class="tg-c3ow">H</td>
  </tr>
  <tr>
    <td class="tg-c3ow">GND</td>
    <td class="tg-c3ow">B1 - Across resistor 10K</td>
  </tr>
</table>

&ensp;

<style type="text/css">
.tg  {border-collapse:collapse;border-spacing:0;}
.tg td{font-family:Arial, sans-serif;font-size:14px;padding:10px 5px;border-style:solid;border-width:1px;overflow:hidden;word-break:normal;border-color:black;}
.tg th{font-family:Arial, sans-serif;font-size:14px;font-weight:normal;padding:10px 5px;border-style:solid;border-width:1px;overflow:hidden;word-break:normal;border-color:black;}
.tg .tg-u8t5{font-family:Tahoma, Geneva, sans-serif !important;;text-align:center}
.tg .tg-0lax{text-align:left;vertical-align:top}
</style>
<table class="tg">
  <tr>
    <th class="tg-u8t5"><span style="font-weight:bold">Connection Instructions</span></th>
  </tr>
  <tr>
    <td class="tg-0lax">- Place the etape MQ2 gas sensor to any of the analog pins A1, A2, A3 and A4.</td>
  </tr>
  <tr>
    <td class="tg-0lax">- Here we are using A1.</td>
  </tr>
  <tr>
    <td class="tg-0lax">- Using a breadboard connect a pin A, pin H, pin A1 to Vcc in Sensything.</td>
  </tr>
  <tr>
    <td class="tg-0lax">- Connect pin B of MQ2 with Analog1 in Sensything.</td>
  </tr>
  <tr>
    <td class="tg-0lax">- Using a breadboard connect a resistor between pin B1 in sensor and GND in the breadboard.</td>
  </tr>
  <tr>
    <td class="tg-0lax">- Connect GND across the resistor from pin B1 with the GND pin in Sensything.</td>
  </tr>
</table>

##### * Excerpts from the code:

```c
float vout = (float)((ads1220_data_32*VFSR*1000)/FSR); 
sensor_volt= vout /1024*5.0;                              // Measuring mq2 gas sensor voltage
printf("Sensor voltage: %f \n",sensor_volt);
RS_gas = (5.0-sensor_volt)/sensor_volt;                  // Calculating gas concentration
printf("Gas Concentration : %f \n",RS_gas );
int32_t ble_vout = (int32_t) (sensor_volt * 100);           // Sending the sensor value through ble
```

[Download the Smoke sensor code](https://www.google.com/url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)

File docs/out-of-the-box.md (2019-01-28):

---
menu: Out of the box Sensything
parent: getting-started.md
weight: 0
---
### Sensything- “Out of the Box”
One unique feature that stands out with the Sensything is its “out of the box” approach. You may wonder what is so unique about it. Where else can you find a board that you can immediately use once you unbox it. The board is **“READY TO USE”**. For all, you eager enthusiasts, who cannot wait to explore new hardware then do go for it. We would be happy to hear from you!

#### What’s in the box?
* 1x Sensything main Board
* 1x 1000 mAH, 3.7V Li-Po battery
* 10x alligator cables
* 1x micro USB cable

If you have purchased the *Sensything - board only* version then you will have to bring your own battery, and cables.
This video throws light on how to set up your Sensything device. Get set Go!
<iframe width="640" height="360" src="https://player.vimeo.com/video/306863926" frameborder="0" allowFullScreen mozallowfullscreen webkitAllowFullScreen></iframe>

#### Making the connections

1) Downloading the App and connecting the device

**Note**: The Sensything App is currently available for Android users on Google Play store. The ios version will be coming soon. Stay tuned for updates!
<iframe width="640" height="360" src="https://player.vimeo.com/video/307040678" frameborder="0" allowFullScreen mozallowfullscreen webkitAllowFullScreen></iframe>

2) Basic connections of Analog sensors

They can be listed as follows:

<style type="text/css">
.tg  {border-collapse:collapse;border-spacing:0;}
.tg td{font-family:Arial, sans-serif;font-size:14px;padding:10px 5px;border-style:solid;border-width:1px;overflow:hidden;word-break:normal;border-color:black;}
.tg th{font-family:Arial, sans-serif;font-size:14px;font-weight:normal;padding:10px 5px;border-style:solid;border-width:1px;overflow:hidden;word-break:normal;border-color:black;}
.tg .tg-s6z2{text-align:center}
.tg .tg-baqh{text-align:center;vertical-align:top}
.tg .tg-s268{text-align:left}
.tg .tg-0lax{text-align:left;vertical-align:top}
</style>
<table class="tg">
  <tr>
    <th class="tg-s268"><span style="font-weight:600">Sensything pin label</span></th>
    <th class="tg-s6z2"><span style="font-weight:600">Analog Channel</span></th>
  </tr>
  <tr>
    <td class="tg-s6z2">A1</td>
    <td class="tg-s6z2">Channel 1</td>
  </tr>
  <tr>
    <td class="tg-baqh">A2</td>
    <td class="tg-baqh">Channel 2</td>
  </tr>
  <tr>
    <td class="tg-baqh">A3</td>
    <td class="tg-baqh">Channel 3</td>
  </tr>
  <tr>
    <td class="tg-baqh">A4</td>
    <td class="tg-baqh">Channel 4</td>
  </tr>
  <tr>
    <td class="tg-baqh">3V3</td>
    <td class="tg-0lax">Supply - Board which supports 3.3V</td>
  </tr>
  <tr>
    <td class="tg-baqh">GND</td>
    <td class="tg-baqh">Ground</td>
  </tr>
</table>

A short video suggests how to connect a basic analog sensor like the Piezo vibration sensor to Sensything.

<iframe width="640" height="360" src="https://player.vimeo.com/video/307550473" frameborder="0" allowFullScreen mozallowfullscreen webkitAllowFullScreen></iframe>

#### Understanding the Sensything Application

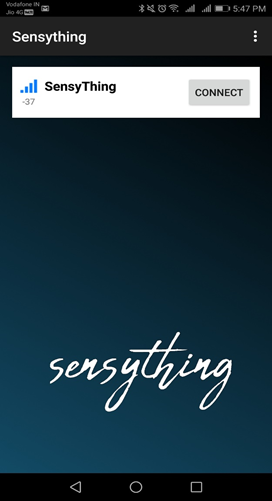
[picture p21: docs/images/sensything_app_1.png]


This above image is a screenshot of the opening page of the Application. This page displays the following information
* Details of the detected Sensything device
* The"Connect" option for the device.

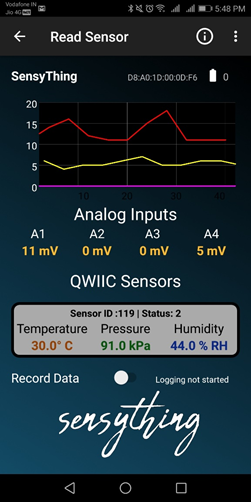
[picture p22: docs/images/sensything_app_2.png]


The main page of the Application can be segmented as follows:
* **Graphical representation** - This depicts the changes in the readings of the sensors. All major and minor fluctuations are picked up.
* **Analog channels** - The four channels gives the ADC values received from the plugins on the board.
* **Qwiic section** - In case any qwiic connection is made the values will be shown there.
* **Data logging** - Using the Application you can log your data so that the data is saved directly to your mobile device.

**Note**: On the right-hand corner there is a battery indicator, this detects the level of charge in the Sensything device.

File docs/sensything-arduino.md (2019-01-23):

---
parent: getting-started.md
menu: Using with Arduino
weight: 1
---

### Using with Arduino

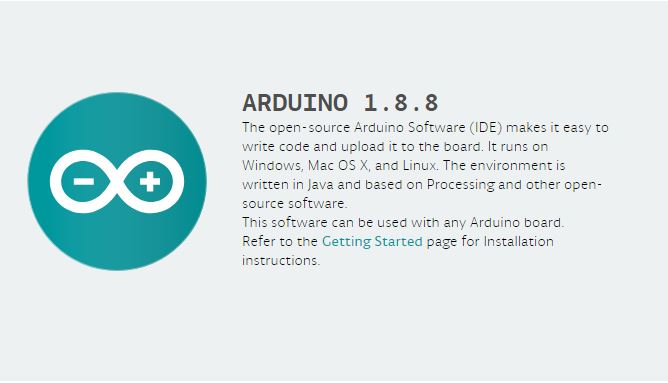
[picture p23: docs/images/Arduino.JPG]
  

Now that you have the Sensything device in your hand, you need to program it first. At a beginner level, we would recommend you to begin with the Arduino IDE. Using this development platform, you can program Sensything and make it your very own Data Acquisition device. You can use any sensor and collect data, that can be displayed in the serial monitor. We have listed down a list of steps that can guide you in setting up the Arduino for your Sensything device. 

#### Setting up Arduino for ESP32

**Step 1: Download and Install the IDE**

The Arduino Software (IDE) allows you to write programs and upload them to your Sensything. Now you require Arduino Desktop IDE. You can download the latest version for Windows, Linux and Mac OS using the below link.
[Download the Arduino IDE](https://www.arduino.cc/en/Main/Software#download)

**Note**: Once you have downloaded, install the IDE and ensure that you enable most (if not all) of the options, including the drivers.

**Step 2: Get the Sensything COM Port Number**

Next, you will need to connect the Sensything board to a system. This is done via a USB connection. When the Sensything is connected, the operating system should recognize the board as a generic COM port. The easiest way to do this is to type **Device manager** into Windows Search and select Device Manager when it shows.

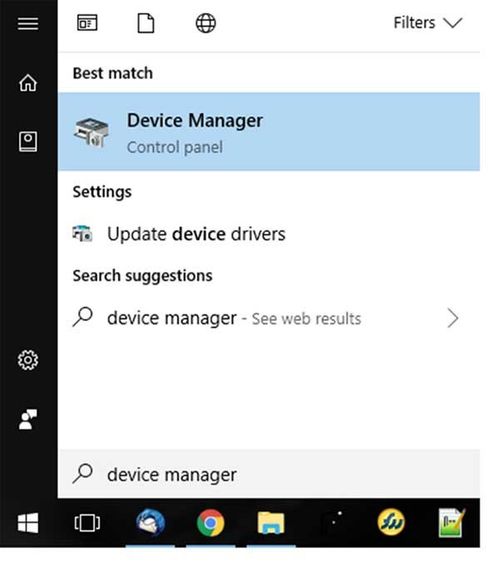
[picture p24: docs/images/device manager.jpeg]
device manager


In the Device Manager window, look for a device under Ports (COM & LPT) and chances are the Arduino will be the only device on the list.

**Step 3: Configure the IDE**

Now that we have determined the COM port that the Arduino is on, its time to load the Arduino IDE and configure it to use the same device and port. You have to install the esp32 platform in the Arduino IDE to find an esp32 board in board manager. For installing esp32 platform follow up the link:

[Installing ESP32 Platform in Boards Manager](https://github.com/espressif/arduino-esp32/blob/master/docs/arduino-ide/boards_manager.md)

You can start by loading the IDE. When it is loaded, navigate to **Tools > Board > Esp32 dev module**.

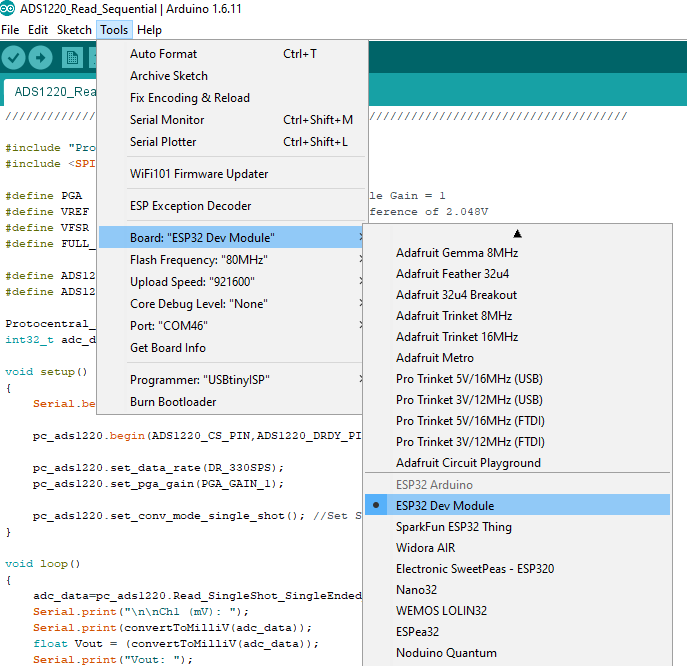
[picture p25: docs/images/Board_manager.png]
Board_manager


Next, you must tell the IDE which COM port the Sensything is on. To do this, navigate to **Tools > Port > COM51**. Obviously, if your Sensything is on a different port, select that port instead.

port_selecting

**Step 4: Writing my first code to Sensything**

A header file is generally used to define all the functions, variables and constants contained in any function library. Define the pin number of **ads1220 Chip select** and **DRDY**.

```c
#include "Protocentral_ADS1220.h"
#define ADS1220_CS_PIN    4
#define ADS1220_DRDY_PIN  34
```
Initialize the onboard ADS1220 ADC with begin
```c
void setup()
{
  Serial.begin(9600);

  pc_ads1220.begin(ADS1220_CS_PIN,ADS1220_DRDY_PIN);

  pc_ads1220.set_data_rate(DR_330SPS);
  pc_ads1220.set_pga_gain(PGA_GAIN_1);
  pc_ads1220.set_conv_mode_single_shot(); //Set Single shot mode
 }
```
In the loop function below we get the ADC data for Channel 0, the same logic can be applied to read channel 1, channel 2 and channel 3.

```c
void loop()
{
  adc_data=pc_ads1220.Read_SingleShot_SingleEnded_WaitForData(MUX_SE_CH0);
  Serial.print("\n\nCh1 (mV): ");
  Serial.print(convertToMilliV(adc_data));
  delay(100);  
}
```  
Converting the ADC data into millivolt
```c
float convertToMilliV(int32_t i32data)
{
    return (float)((i32data*VFSR*1000)/FULL_SCALE);
}
```
Getting the above code is as easy as installing the Arduino library **https://github.com/Protocentral/Protocentral_ADS1220** and loading the simple ads1220 data acquisition example from the Arduino IDE's menu:**File > Open > Protocentral_ADS1220**.



**Step 5: Compiling and Uploading**

Compile the code and check for compilation without error and upload the code to Sensything so as to print the 4-channel analog readings in the Serial Monitor.



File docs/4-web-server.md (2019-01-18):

---
menu: Sensything as a Web server
parent: getting-started.md
weight: 3
---
### Sensything as a Web server

The web server came into being to eliminate the need to install any software or application to display sensor values. With a small addition to the programming section, you would be able to read the sensor values on your system. To get started you can follow the basic steps mentioned below to understand how it would work.

#### How to Use Sensything as a Web Server

By equipping Sensything you can turn it into a web server. By accessing that server with a browser running on any computer connected to the same network or the soft-AP available in sensything you can

**Read a value of a sensor (using simple HTML)**

**Step 1: Writing Code to Web Server**

Now you can upload/write the code, and it will work straight away. You can create an HTML page for displaying the sensor values, read the HTML contents and send the analog values to the web page.
```c

 String adcValue = MAIN_page; //Read HTML contents
 server.send(200, "text/html", adcValue); //Send web page

```

The ADC value is read from analog channels of sensything and the ADC data is sent to the browser while HTTP data request from the server.

 ```c

  adc_data=pc_ads1220.Read_SingleShot_SingleEnded_WaitForData(MUX_SE_CH0);
  String adcValue = String(convertToMilliV(adc_data));
  server.send(200, "text/plane", adcValue); //Send ADC value only to client ajax request

 ```
 Creating an HTTP request object in the browser to request ADC value from server and process the returned ADC value to update the web page.

 ```c
  var xhttp = new XMLHttpRequest();
  xhttp.onreadystatechange = function() {
  if (this.readyState == 4 && this.status == 200) {
  document.getElementById("ADCValue").innerHTML =
  this.responseText;
```
Don't forget to check if you have the ESP32 Dev Module(Sensything) board and Sensything COM port selected, otherwise you will get an error when trying to upload. Open the Serial Monitor at a baud rate of 115200.

**Step 2: Finding the ESP IP Address**

Press the sensything ON/OFF button and it will output the ESP IP address once the code is uploaded on the Serial Monitor.

Arduino serial monitor

**Step 3: Accessing the Web Server**

Open your browser, type the ESP IP address, and you’ll see the following page. This page is sent by the sensything when you make a request on the ESP IP address. If you take a look at the browser, you can see what is going on in the background. The ESP receives an HTTP request from a new client and displays the analog values.

**Step 4: Testing the Web Server**

Let’s test the web server. Connect the analog sensors with sensything and get the live readings of channels in the web server.



[Download the Web server code](https://github.com/Protocentral/protocentral_sensything/tree/master/software/Sensything_Arduino/sensything_web/examples/sensything_web)

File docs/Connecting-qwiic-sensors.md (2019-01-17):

---
menu: Connecting-qwiic-sensors
weight: 3
---

### **Why Qwiic?**



[Qwiic functionality](https://www.sparkfun.com/qwiic) was first devised by Sparkfun. If you ask why Qwiic? It makes prototyping easy and less complex. With Sensything we have built-in support for popular Qwiic sensors. With a list of sensors and connectors in the Qwiic section, you can use multiple sensors at the same time using the [Daisy chain](https://en.wikipedia.org/wiki/Daisy_chain_(electrical_engineering) method. With two Qwiic slots provided on the board, you can keep going.

#### Using Qwiic connect system with Sensything

The Qwiic connect option with Sensything makes sensor plugins a whole lot easier. With the board in hand, we would be able to pre-program for a list of Qwiic sensor. This would make it more suitable to plug in, detect the sensor and the load the code automatically. We will be updating this section. 



You can find an example for a Qwiic sensor experiment in

- [Experiment 3](https://sensything.protocentral.com/3-pressure-sensor.html)

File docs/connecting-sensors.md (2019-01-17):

---
menu: Connecting sensors
weight: 2
---

A sensor is a measure of the changes that occur in the physical environment or it is your chance to interface with the physical world. It collects this data and provides an analog voltage as an output. The output range usually varies from 0 to 5 volts, for most of them.

Sensything offers you the platform to explore Sensor based Applications in the following areas where data collection and data monitoring for research and developmental purposes are essential:-

- **Indoor or Home based**
- **Environmental**
- **Laboratory or Research**
- **Industrial**

In the case of Sensything, Analog and Qwiic sensors can be connected.

**Analog**

An Analog sensor has the ability to measure the variable in a continuous manner and by detecting the proportional value. In other words, Analog is directly related to precision. To enhance this capability the Sensything has an inbuilt 24-bit ADC called ADS1220 for quick and precision based sensor readings. In case your projects are reliant on accurate and precision values for your varied projects then look no further.

You can find Analog sensor experiments in

- [Experiment 1](https://sensything.protocentral.com/1-alcohol-sensor.html)

- [Experiment 2](https://sensything.protocentral.com/2-etape.html)

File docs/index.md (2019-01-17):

---
menu: Welcome
weight: 0 # smaller weights rise to the top of the menu
---

### Welcome to Sensything

Sensything main image

Sensything is a Data- acquisition board with the added capabilities of ADC precision (ADS1220). The board contains an ESP-32 microcontroller with Qwiic connectivity that is most suitable for IOT applications. Using one single platform to monitor sensor readings along with the support of a BLE Application and Web server just makes it all the more advanced and simplifies solutions.

If you don't already have one, you can now buy Sensything from [Crowd Supply](https://www.crowdsupply.com/protocentral/sensything)

#### HIGHLIGHTS

**Microcontroller**: ESP-PICO-D4 SIP with 4 MB Flash 

**ADC**: Texas Instruments ADS1220 24-bit Sigma-Delta

 **Analog characteristics**:                                                                 
* 4 channels single-ended, 2-channel fully differential                                   
* Full-scale input range: ± 2.048 V to ± 0.016 V (adjustable gain).                      
* Sampling rate: 20 samples/second (SPS) to 2000 SPS.                                    
* Current sources: On-board excitation current sources adjustable from 10 uA to  1500 uA.
* Built-in 2.048 V voltage reference with 5 ppm/°C drift.                                
* Built-in temperature sensor with 0.5°C accuracy.                                       

**Wireless interface**:                                
* 2.4 GHz radio with on-board PCB antenna               
* Wi-Fi station and Access Point (AP) mode              
* Bluetooth 4.2 / Bluetooth Low Energy (BLE) compatible 

**Ports and I/O**:                                            
* Board-edge alligator clip compatible analog input connectors 
* 2x Sparkfun Qwiic-compatible I2C ports                       
* USB-CDC (on-board FT230X)                                    
* 4x general-purpose I/O pins                                  
* 1 WS2812 RGB user-controllable LED for indication            
* MicroSD card slot for on-board data logging                  

**Power supply**:                                                          
* Li-ion battery (3.7 V, 1000 mAH) as power source                       
* On-board USB battery charger                                           
* On-board 5 V DC/DC boost converter with low-noise LDO for analog power 
* 3.3 V digital supply voltage                                           

**Dimensions**: 47x57 mm (length, width), 5 mm height (board only), 12 mm height (with included battery stacked)

#### Modes of operation

##### * BLE mode 

Sensything is well equipped for BLE data acquisition. By this, we mean that the sensor is able to connect an Application and transfer the sensor readings. The mode of transmission would be BLE. It limits the complexity of data transfer and also improves the chances of retaining the data in a quick manner. The Sensything Application available on Google store for Android users for free. You can not only read values but also log your data using the Application. The data thus collected will be stored directly on to your phone.

 
 
##### * Webserver Mode

In case you wish to limit the number of downloads and software to display the sensor values then you could opt for the Web server. By making small changes in the code you could connect your device and display sensor values on your system. By pointing your browser to a site you can display the values without any internet connection. You can set up the Web server with the Arduino and ESP-IDF as shown in the image below.

Webserver- mode

##### * Developer Mode

Sensything can be easily programmed. If you are a beginner then you could choose the Arduino IDE to program the board for any sensor. On the other hand, if you are the high-end developer then you could look at the ESP-IDF for programming the mode. Easy and flexible! That is what the Sensything board was designed to do, you can mold it into a device of your choice with very less programming knowledge required.

Developer mode

##### * Data logger mode

Sensything can function as a data logger with the inbuilt SD card option in the board. The inbuilt storage option improves the chances for a wider scope and flexibility in storing sensor readings. Along with this, the data transfer rate becomes faster long with low battery consumption. The data logging option is also available in the Sensything Application.



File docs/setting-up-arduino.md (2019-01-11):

---
parent: getting-started.md
menu: Setting up Arduino
---

# Setting up Arduino for ESP32

Before you start controlling the world around you, you'll need to set up the software to program your Sensything.

### Step 1: Download and Install the IDE
The Arduino Software (IDE) allows you to write programs and upload them to your Sensything. Now you require arduino Desktop IDE.You can download the latest version for windows, linux and Mac OS using the below link .

[Download the Arduino IDE](https://www.arduino.cc/en/Main/Software#download)

**Note**: Once you have downloaded, install the IDE and ensure that you enable most (if not all) of the options, including the drivers.

### Step 2: Get the Sensything COM Port Number
Next you will need to connect the Sensything board to a system. This is done via a USB connection. When the Sensything is connected, the operating system should recognize the board as a generic COM port. The easiest way to do this is to type **Device manager** into Windows Search and select Device Manager when it shows.

device manager

In the Device Manager window, look for a device under Ports (COM & LPT) and chances are the Arduino will be the only device on the list.

### Step 3: Configure the IDE
Now that we have determined the COM port that the Arduino is on, its time to load the Arduino IDE and configure it to use the same device and port.You have to install the esp32 platform in the Arduino IDE to find esp32 board in board manager.For installing esp32 platform follow up th link:

[Installing ESP32](https://github.com/espressif/arduino-esp32/blob/master/docs/arduino-ide/boards_manager.md)

You can start by loading the IDE. When it is loaded, navigate to **Tools > Board > Esp32 dev module**.

IDE

Next you must tell the IDE which COM port the Sensything is on. To do this, navigate to **Tools > Port > COM51**. Obviously, if your Sensything is on a different port, select that port instead.

selecting port

### Step 4: Writing my first code to Sensything
A header file is generally used to define all the functions, variables and constants contained in any function library. Define the pin number of **ads1220 Chip select** and **DRDY**.

```c
#include "Protocentral_ADS1220.h"
#define ADS1220_CS_PIN    4
#define ADS1220_DRDY_PIN  34
```
Initialize the onboard ADS1220 ADC with begin
```c
void setup()
{
  Serial.begin(9600);

  pc_ads1220.begin(ADS1220_CS_PIN,ADS1220_DRDY_PIN);

  pc_ads1220.set_data_rate(DR_330SPS);
  pc_ads1220.set_pga_gain(PGA_GAIN_1);
  pc_ads1220.set_conv_mode_single_shot(); //Set Single shot mode
 }
```
In the loop function below we get the ADC data for Channel 0, the same logic can be applied to read channel 1, channel 2 and channel 3.

```c
void loop()
{
  adc_data=pc_ads1220.Read_SingleShot_SingleEnded_WaitForData(MUX_SE_CH0);
  Serial.print("\n\nCh1 (mV): ");
  Serial.print(convertToMilliV(adc_data));
  delay(100);  
}
```  
Converting the adc data into millivolt
```c
float convertToMilliV(int32_t i32data)
{
    return (float)((i32data*VFSR*1000)/FULL_SCALE);
}
```
Getting the above code is as easy as installing the Arduino library **https://github.com/Protocentral/Protocentral_ADS1220** and loading the simple ads1220 data acquisition example from  the Arduino IDE's menu:**File > Open > Protocentral_ADS1220**.



## Step 5: Compiling and Uploading

Compile the code and check for compilation without error and upload the code to Sensything so as to print the 4-channel analog readings in the Serial Monitor.



Its time to get started with some sensors to get the Real time output. We have showcased this in the following experiments with both Analog and Qwiic sensors.

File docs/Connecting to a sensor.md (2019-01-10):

---
menu: Connecting to a sensor
weight: 2
---

A sensor is a measure of the changes that occur in the physical environment or it is your chance to interface with the physical world. It collects this data and provides an analog voltage as an output. The output range usually varies from 0 to 5 volts, for most of them.

In case of Sensything, the type of sensors to be used are:-

**Analog**

An Analog sensor has the ability to measure the variable in a continuous manner and by detecting the proportional value. In other words Analog is directly related to precision. To enhance this capability the Sensything has an inbuilt 24-bit ADC called ADS1220 for quick and precision based sensor readings. In case your projects are reliant on accurate and precision values for your varied proects then look no further.

You can find Analog sensor experiments in 

[Experiment 1](https://sensything.protocentral.com/1-alcohol-sensor.html)

[Experiment 2](https://sensything.protocentral.com/2-etape.html)

**Qwiic**

[Qwiic functionality](https://www.sparkfun.com/qwiic) was first devised by Sparkfun. If you ask why Qwiic? It makes prototyping easy and less complex.With Sensything we have built-in support for popular Qwiic sensors. With a list of sensors and connectors in the Qwiic section, you can use multiple sensors at the same time using the [Daisy chain](https://en.wikipedia.org/wiki/Daisy_chain_(electrical_engineering)) method. With two Qwiic slots provided on the board, you can keep going.

You can find Qwiic sensor experiments in 

[Experiment 3](https://sensything.protocentral.com/3-pressure-sensor.html)

Sensything offers you the platform to explore Sensor based Applications in the following areas where data collection and data monitoring for research and developmental purposes are essential:-

- **Indoor or Home based**
- **Environmental**
- **Laboratory or Research**
- **Industrial**

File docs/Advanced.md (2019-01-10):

---
menu: Advanced Sensything
weight: 3 # smaller weights rise to the top of the menu
---

# Advanced

This document is intended to help users set up the software environment of applications using Espressif ESP32. Through a simple step-by-step process to illustrate how to use ESP-IDF(Espressif IoT Development Framework).

## What You Need
To develop applications for ESP32 you need:
* PC loaded with either Windows, Linux or Mac operating system
* Toolchain to build the Application for ESP32
* ESP-IDF that essentially contains API for ESP32 and scripts to operate the Toolchain
* A text editor to write programs (Projects) in C

## Preparation for development

### Setting up the toolchain

Windows doesn’t have a built-in “make” environment, so as well as installing the toolchain you will need a GNU-compatible environment. We can use the MSYS2 environment to provide this environment.
Toolchain Setup
The quick setup is to download the Windows all-in-one toolchain & MSYS2 zip file from dl.espressif.com:
https://dl.espressif.com/dl/esp32_win32_msys2_environment_and_toolchain-20180110.zip.

**Procedures**:
1.	Open msys32 mingw32.exe terminal window.
2.	Create new directory
```c
mkdir -p /home
```
3.	The newly created directory can be moved by typing cd ~/esp
```c
cd /home
```
### Getting ESP-IDF

Besides the toolchain (that contains programs to compile and build the application), you also need ESP32 specific API / libraries. They are provided by Espressif in ESP-IDF repository. To get it, open terminal, navigate to the directory you want to put ESP-IDF, and clone it using git clone command:
To get all the sub-modules run another command
```c
cd /home/esp-idf
git submodule update --init
 ```

Setup path to ESP-IDF – toolchain program access ESP-IDF using IDF_PATH.Remember to replace back-slashes with forward-slashes in the original Windows path.
```c
printenv IDF_PATH
```
To setup the software environment and get esp-idf follow the instructions given in the link below.

https://docs.espressif.com/projects/esp-idf/en/latest/get-started/index.html#

For further information/queries connect with us at sales@protocentral.com.

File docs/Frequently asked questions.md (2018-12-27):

# Basic pointers

* How do I turn on the device?

switch

Firstly, connect the battery to the Sensything board, then switch on the board.

| Situation | Solution |
|---|---|
| How do I charge the battery? | Ensure that the battery is plugged to the Board and then connect the USB cable.  You can use a 5v power adapter as the power source. |
| How can I determine the BLE communication? | Once connected through the BLE, the RGB LED will turn OFF.  |
| | When it is disconnected then the RGB LED turns ON |

# Troubleshooting 

| Issue | Solution |
|---|---|
| If the port is not found? | You can unplug the USB cable and plug it again |
| | Try changing the USB cable |
| | Try with a different system |
| If there is an uploading problem | Check whether the switch is turned ON |
| | Select the COM port and board in the board manager. |
| | Check for the latest version of arduino ide and esp-idf |
| If the RGB does not power up | Download and upload the latest firmware from Github |
| Issues with channel values ? | |
| -> No values | Download and upload the latest firmware from github |
| -> Wrong values | Try giving fixed input values for the channels and read |
| -> Noise(Disturbance between channels) | Test if the 3.3V and 5V power source is proper |
| -> Cross talk | If one analog channel is in use the other channels need to be grounded. |
| What if BLE device is not found? | Check if your mobile device supports BLE |
| | Check whether the device is within the prescribed BLE range |
| | Allow the application to turn BLE ON in your device. |

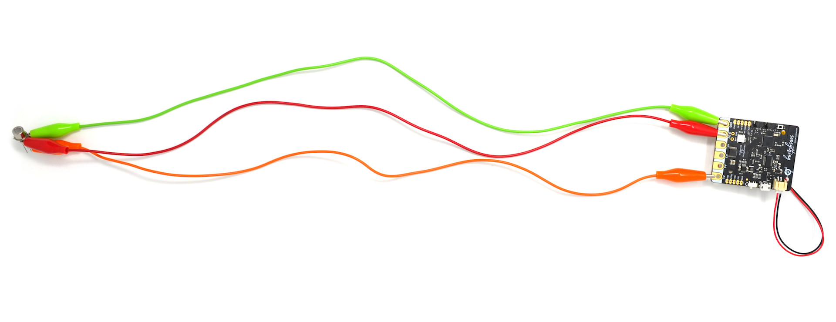
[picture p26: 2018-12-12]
docs/images/sensything-with-sensor-clean.jpg

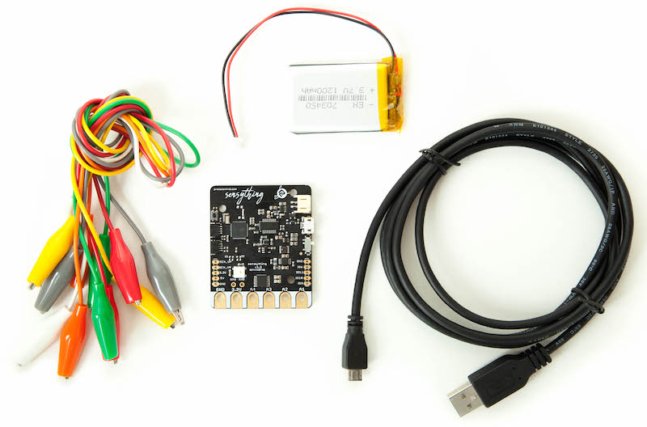
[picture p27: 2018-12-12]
docs/images/sensything-all-items.jpg

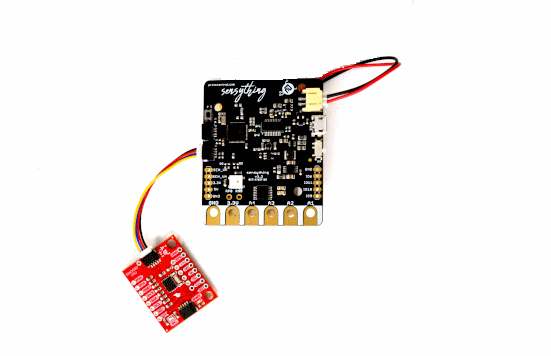
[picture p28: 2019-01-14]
docs/images/Qwiic sensor.gif

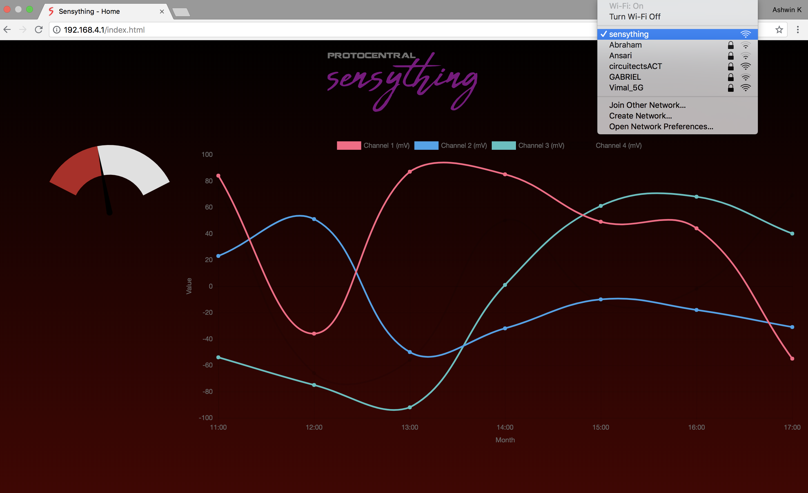
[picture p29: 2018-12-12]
docs/images/sensything-wi-fi-ap-screen1.png

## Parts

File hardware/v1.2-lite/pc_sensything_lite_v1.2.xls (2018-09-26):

Pc_Sensything_Lite
Qty | Value | Parts | Package
6 | 100nF | C2, C6, C7, C11,C60, C62 | C0402
1 | 100nF | C20 | C0603
1 | 1.0uF | C63 | C0402
1 | 10uF | C15 | C0603
1 | 10uF | C13 | C0402
1 | 10uF | C61 | C0805
2 | 15pF | C57, C58 | C0603
1 | 1uF | C72 | C0402
1 | 2.2uF | C67 | C0402
1 | 2.4pF | C48 | C0603
2 | 4.7u | C64, C65 | C0805
1 | 5.6pF | C49 | C0603
6 | 10K | R3, R4, R5, R18, R19, R23 | R0402
7 | 10k | R9, R10,R6, R8, R11, R25, R26 | R0603
3 | 1K | R12, R13,R17 | R0402
1 | 330R | R16 | R0402
2 | 27R | R14, R15 | R0402
1 | 2.5A/30V | Q2 | SOT23-3
1 | 2.7nH | L1 | L0603
1 | 32.768kHz | Y1 | CRYSTAL-SMD-3.2X1.5MM
1 | AP2112K-3.3V | U8 | SOT23-5
1 | BAT20J | D1 | SOD-323
1 | CY8C29666_QFN48 | IC1 | QFN48
1 | DNP | C8 | C0603
2 | DNP | D2, D3 | CHIPLED_0603
3 | DNP | R1, R2, R22 | R0402
1 | FTS31XS-U | U1 | SSOP20_L
1 | KMR2 | SW2 | BTN_KMR2_4.6X2.8
1 | MBT3904DW1T1 | Q1 | SC70-6
1 | MCP73831 | U3 | SOT23-5
1 | MICRO-B | JP7 | MICRO-B
1 | PCM12SMTR | S2 | SWITCH-SPST-SMD-A
1 | RED | CHG2 | CHIPLED_0603
1 | WS2812B5050 | LED1 | WS2812B
2 |  | J1, J4 | 1X04_1MM_RA

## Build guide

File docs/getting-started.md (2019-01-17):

---
menu: Getting Started
weight: 1 # smaller weights rise to the top of the menu
---
### Sensything - Data Acquistion tool

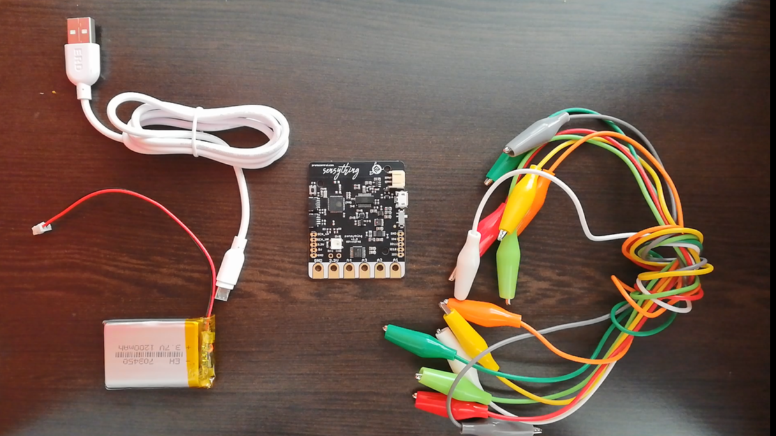
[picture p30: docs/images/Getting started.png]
Getting started


Sensything being an open source device, is not like any other DAQ tool. It takes the element of data acquisition to newer heights with inbuilt capabilities in the board. With advanced wireless communication like BLE and Wifi, collecting sensor has never been easier and simplified. With such highlights, it is only right for the user to maximize their gain with this device. We have put in some pointers to help the user to get the most from Sensything.

We urge the user to stay open to new ideas and to start exploring..

#### How to get the best out of your Sensything?

* **ADC Precison values**

Any sensor reading needs to be accurate and reliable. Only then can any individual understand and question his/her surrounding.Real-time data matters and that is how accuracy becomes all the more important. Without using an external ADC, Sensything helps you to collect data with a high level of accuracy. Monitoring sensor data could not have become easier.

* **Flexibility in using sensors**

The board itself allows for direct plugins without a requirement for a breadboard as such. As for the Analog pins on the board, the alligator cables help to connect Analog sensors. In the case of Qwiic, by using a Qwiic connector to a Qwiiic sensor you are good to go. Using the Arduino IDE or the ESP-idf you could program the board for the sensor of your choice.

* **Data Storage**

Sensything offers you a platform to store your sensor data both safe and in a secure manner. Collecting data is a tough task not to mention its important to protect it, so as to avoid loss of data and to avoid directing data through unsafe channels. The data can either be logged on to your mobile device or using a removable storage option (inbuilt SD card slot)

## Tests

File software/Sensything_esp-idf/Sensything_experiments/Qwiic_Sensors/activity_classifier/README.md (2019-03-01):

This is an example of how to use libesphttpd with the Espressif FreeRTOS SDK.

# ESP32

Ensure that you have updated submodules appropriately:

```git submodule update --init --recursive```

Run the esp32 makefile (make sure you enable the esphttpd component) and build

```make```

Load onto your esp32 and monitor

```make flash&&make monitor```

# ESP8266

Building for ESP8266 requires a bit more work.

Ensure that you are defining SDK_PATH to point at the ESP8266_RTOS_SDK:

```export SDK_PATH=/some/path/ESP8266_RTOS_SDK```

Update your path to point at your xtensa-lx106 tool chain, something like:

```export PATH=/some/path/esp-open-sdk/xtensa-lx106-elf/bin:$PATH```

If you don't have these tools you can get the SDK from:
https://github.com/espressif/ESP8266_RTOS_SDK

And you can get the crosstool source (you'll have to build the toolchain yourself) from :
https://github.com/pfalcon/esp-open-sdk

And then you should be able to build with:

```make -f Makefile.esp8266 USE_OPENSDK=yes FREERTOS=yes -C libesphttpd```

# Old notes

(I'm not sure these still apply, I mostly build for ESP32, feedback and pull requests welcome in this area)

The Makefile in this example isn't perfect yet: something is going wrong with the dependency
checking, causing files that have changed not always being recompiled. To work around this,
please run a
```make clean && make -C libesphttpd && make```
before running
```make flash```

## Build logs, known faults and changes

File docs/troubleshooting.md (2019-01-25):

---
menu: Troubleshooting
weight: 5 # smaller weights rise to the top of the menu
---

### Troubleshooting

As you learn and explore our device, you may encounter some hiccups along the way. We hope to extend our full Technical support and guidance. We have listed out some of the common issues you may come across. Do send in your queries to **sales@protocentral.com**. All your queries will be addressed within 24 hours.

**Note**: This section will be updated constantly.

<style type="text/css">
.tg  {border-collapse:collapse;border-spacing:0;}
.tg td{font-family:Arial, sans-serif;font-size:14px;padding:10px 5px;border-style:solid;border-width:1px;overflow:hidden;word-break:normal;border-color:black;}
.tg th{font-family:Arial, sans-serif;font-size:14px;font-weight:normal;padding:10px 5px;border-style:solid;border-width:1px;overflow:hidden;word-break:normal;border-color:black;}
.tg .tg-ui9f{font-size:16px;font-family:Tahoma, Geneva, sans-serif !important;;border-color:inherit;text-align:center;vertical-align:top}
.tg .tg-0pky{border-color:inherit;text-align:left;vertical-align:top}
</style>
<table class="tg">
  <tr>
    <th class="tg-ui9f"><span style="font-weight:bold">Issue</span></th>
    <th class="tg-ui9f"><span style="font-weight:bold">Solution</span></th>
  </tr>
  <tr>
    <td class="tg-0pky">* If the port is not found?</td>
    <td class="tg-0pky">- You can unplug the USB cable and plug it again.</td>
  </tr>
  <tr>
    <td class="tg-0pky"></td>
    <td class="tg-0pky">- Try changing the USB cable</td>
  </tr>
  <tr>
    <td class="tg-0pky"></td>
    <td class="tg-0pky">- Try changing the USB cable</td>
  </tr>
  <tr>
    <td class="tg-0pky">* If there is an uploading problem?</td>
    <td class="tg-0pky">- Check whether the switch is turned ON.</td>
  </tr>
  <tr>
    <td class="tg-0pky"></td>
    <td class="tg-0pky">- Select the COM port and board in the board manager.</td>
  </tr>
  <tr>
    <td class="tg-0pky"></td>
    <td class="tg-0pky">- Check for the latest version of arduino ide and esp-idf.</td>
  </tr>
  <tr>
    <td class="tg-0pky">* If the RGB does not power up?</td>
    <td class="tg-0pky">- Download and upload the latest firmware from Github.</td>
  </tr>
  <tr>
    <td class="tg-0pky">* Issues with channel values ?</td>
    <td class="tg-0pky"></td>
  </tr>
  <tr>
    <td class="tg-0pky">-&gt; No values</td>
    <td class="tg-0pky">- Download and upload the latest firmware from Github,</td>
  </tr>
  <tr>
    <td class="tg-0pky">-&gt; Wrong values</td>
    <td class="tg-0pky">- Try giving fixed input values for the channels and read.</td>
  </tr>
  <tr>
    <td class="tg-0pky">-&gt; Noise(Disturbance between channels)</td>
    <td class="tg-0pky">- Test if the 3.3V and 5V power source is proper.</td>
  </tr>
  <tr>
    <td class="tg-0pky">-&gt; Cross talk</td>
    <td class="tg-0pky">- If one analog channel is in use the other channels need to be grounded.</td>
  </tr>
  <tr>
    <td class="tg-0pky">* What if BLE device is not found?</td>
    <td class="tg-0pky">- Check if your mobile device supports BLE.</td>
  </tr>
  <tr>
    <td class="tg-0pky"></td>
    <td class="tg-0pky">- Check whether the device is within the prescribed BLE range.</td>
  </tr>
  <tr>
    <td class="tg-0pky"></td>
    <td class="tg-0pky">- Allow the application to turn BLE ON in your device.</td>
  </tr>
</table>

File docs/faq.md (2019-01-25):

---
menu: FAQ
weight: 4 # smaller weights rise to the top of the menu
---

### Frequently asked questions

* How do I turn on the device?

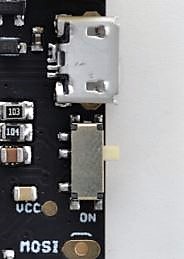
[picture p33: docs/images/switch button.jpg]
  

Firstly, connect the battery to the Sensything board, then switch on the board.

<style type="text/css">
.tg  {border-collapse:collapse;border-spacing:0;}
.tg td{font-family:Arial, sans-serif;font-size:14px;padding:10px 5px;border-style:solid;border-width:1px;overflow:hidden;word-break:normal;border-color:black;}
.tg th{font-family:Arial, sans-serif;font-size:14px;font-weight:normal;padding:10px 5px;border-style:solid;border-width:1px;overflow:hidden;word-break:normal;border-color:black;}
.tg .tg-ui9f{font-size:16px;font-family:Tahoma, Geneva, sans-serif !important;;border-color:inherit;text-align:center;vertical-align:top}
.tg .tg-0pky{border-color:inherit;text-align:left;vertical-align:top}
</style>
<table class="tg">
  <tr>
    <th class="tg-ui9f"><span style="font-weight:bold">Question</span></th>
    <th class="tg-ui9f"><span style="font-weight:bold">Solution</span></th>
  </tr>
  <tr>
    <td class="tg-0pky">* Which microcontroller is used?</td>
    <td class="tg-0pky">- The microcontroller used is ESP-PICO-D4 SIP with 4 MB Flash.</td>
  </tr>
  <tr>
    <td class="tg-0pky">* Name of the ADC?</td>
    <td class="tg-0pky">- Texas Instruments ADS1220 24-bit Sigma-Delta</td>
  </tr>
  <tr>
    <td class="tg-0pky">* Is the sensor data accurate?</td>
    <td class="tg-0pky">With an inbuilt ADC,ADS1220 ensures 24-bit resolution for sensor data.</td>
  </tr>
  <tr>
    <td class="tg-0pky">How do I make the Analog connections?</td>
    <td class="tg-0pky">A1 - Channel 1</td>
  </tr>
  <tr>
    <td class="tg-0pky"></td>
    <td class="tg-0pky">A2 - Channel 2</td>
  </tr>
  <tr>
    <td class="tg-0pky"></td>
    <td class="tg-0pky">A3 - Channel 3</td>
  </tr>
  <tr>
    <td class="tg-0pky"></td>
    <td class="tg-0pky">A4 - Channel 4</td>
  </tr>
  <tr>
    <td class="tg-0pky"></td>
    <td class="tg-0pky">3V3 - Supply - Board which supports 3.3V</td>
  </tr>
  <tr>
    <td class="tg-0pky"></td>
    <td class="tg-0pky">GND - Ground</td>
  </tr>
  <tr>
    <td class="tg-0pky">* What is the input range?</td>
    <td class="tg-0pky">- The input range is ± 2.048 V to ± 0.016 V (adjustable gain)</td>
  </tr>
  <tr>
    <td class="tg-0pky">* What is the Sampling rate for Analog?</td>
    <td class="tg-0pky">- The sampling rate is 20 samples/second (SPS) to 2000 SPS.</td>
  </tr>
  <tr>
    <td class="tg-0pky">* What are the current sources?</td>
    <td class="tg-0pky">- There is an On-board excitation current sources adjustable from 10 uA to 1500 uA.</td>
  </tr>
  <tr>
    <td class="tg-0pky">* How many I/O pins are there?</td>
    <td class="tg-0pky">- There are 4 general-purpose I/O pins.</td>
  </tr>
  <tr>
    <td class="tg-0pky">* How can I determine the BLE communication?</td>
    <td class="tg-0pky">- Once connected through the BLE, the RGB LED will turn OFF.</td>
  </tr>
  <tr>
    <td class="tg-0pky"></td>
    <td class="tg-0pky">- When it is disconnected then the RGB LED turns ON.</td>
  </tr>
  <tr>
    <td class="tg-0pky">* What is the digital supply voltage?</td>
    <td class="tg-0pky">- It is 3.3V</td>
  </tr>
  <tr>
    <td class="tg-0pky">* What are the board dimensions?</td>
    <td class="tg-0pky">- 47x57 mm (length, width), 5 mm height (board only), 12 mm height (with included battery stacked)</td>
  </tr>
  <tr>
    <td class="tg-0pky">* Can i use the Qwiic option for connecting sensors?</td>
    <td class="tg-0pky">- There are two Sparkfun Qwiic-compatible I2C ports on board.</td>
  </tr>
  <tr>
    <td class="tg-0pky">* What is the range of wireless frequency?</td>
    <td class="tg-0pky">- There is a 2.4 GHz radio with on-board PCB antenna.</td>
  </tr>
  <tr>
    <td class="tg-0pky">* What is the voltage reference?</td>
    <td class="tg-0pky">- Built-in 2.048 V voltage reference with 5 ppm/°C drift.</td>
  </tr>
  <tr>
    <td class="tg-0pky">* Any inbuilt sensor?</td>
    <td class="tg-0pky">- There is an built-in temperature sensor with 0.5°C accuracy.</td>
  </tr>
  <tr>
    <td class="tg-0pky">* What is the power source?</td>
    <td class="tg-0pky">- There is a Li-ion battery (3.7 V, 1000 mAH) as power source.This would be applicable to those who ordered the basic kits.</td>
  </tr>
  <tr>
    <td class="tg-0pky">* How do I charge the battery?</td>
    <td class="tg-0pky">- There is an On-board USB battery charger.Ensure that the battery is plugged to the board and then connect the USB cable. You can use a 5v power adapter as the power source.</td>
  </tr>
</table>

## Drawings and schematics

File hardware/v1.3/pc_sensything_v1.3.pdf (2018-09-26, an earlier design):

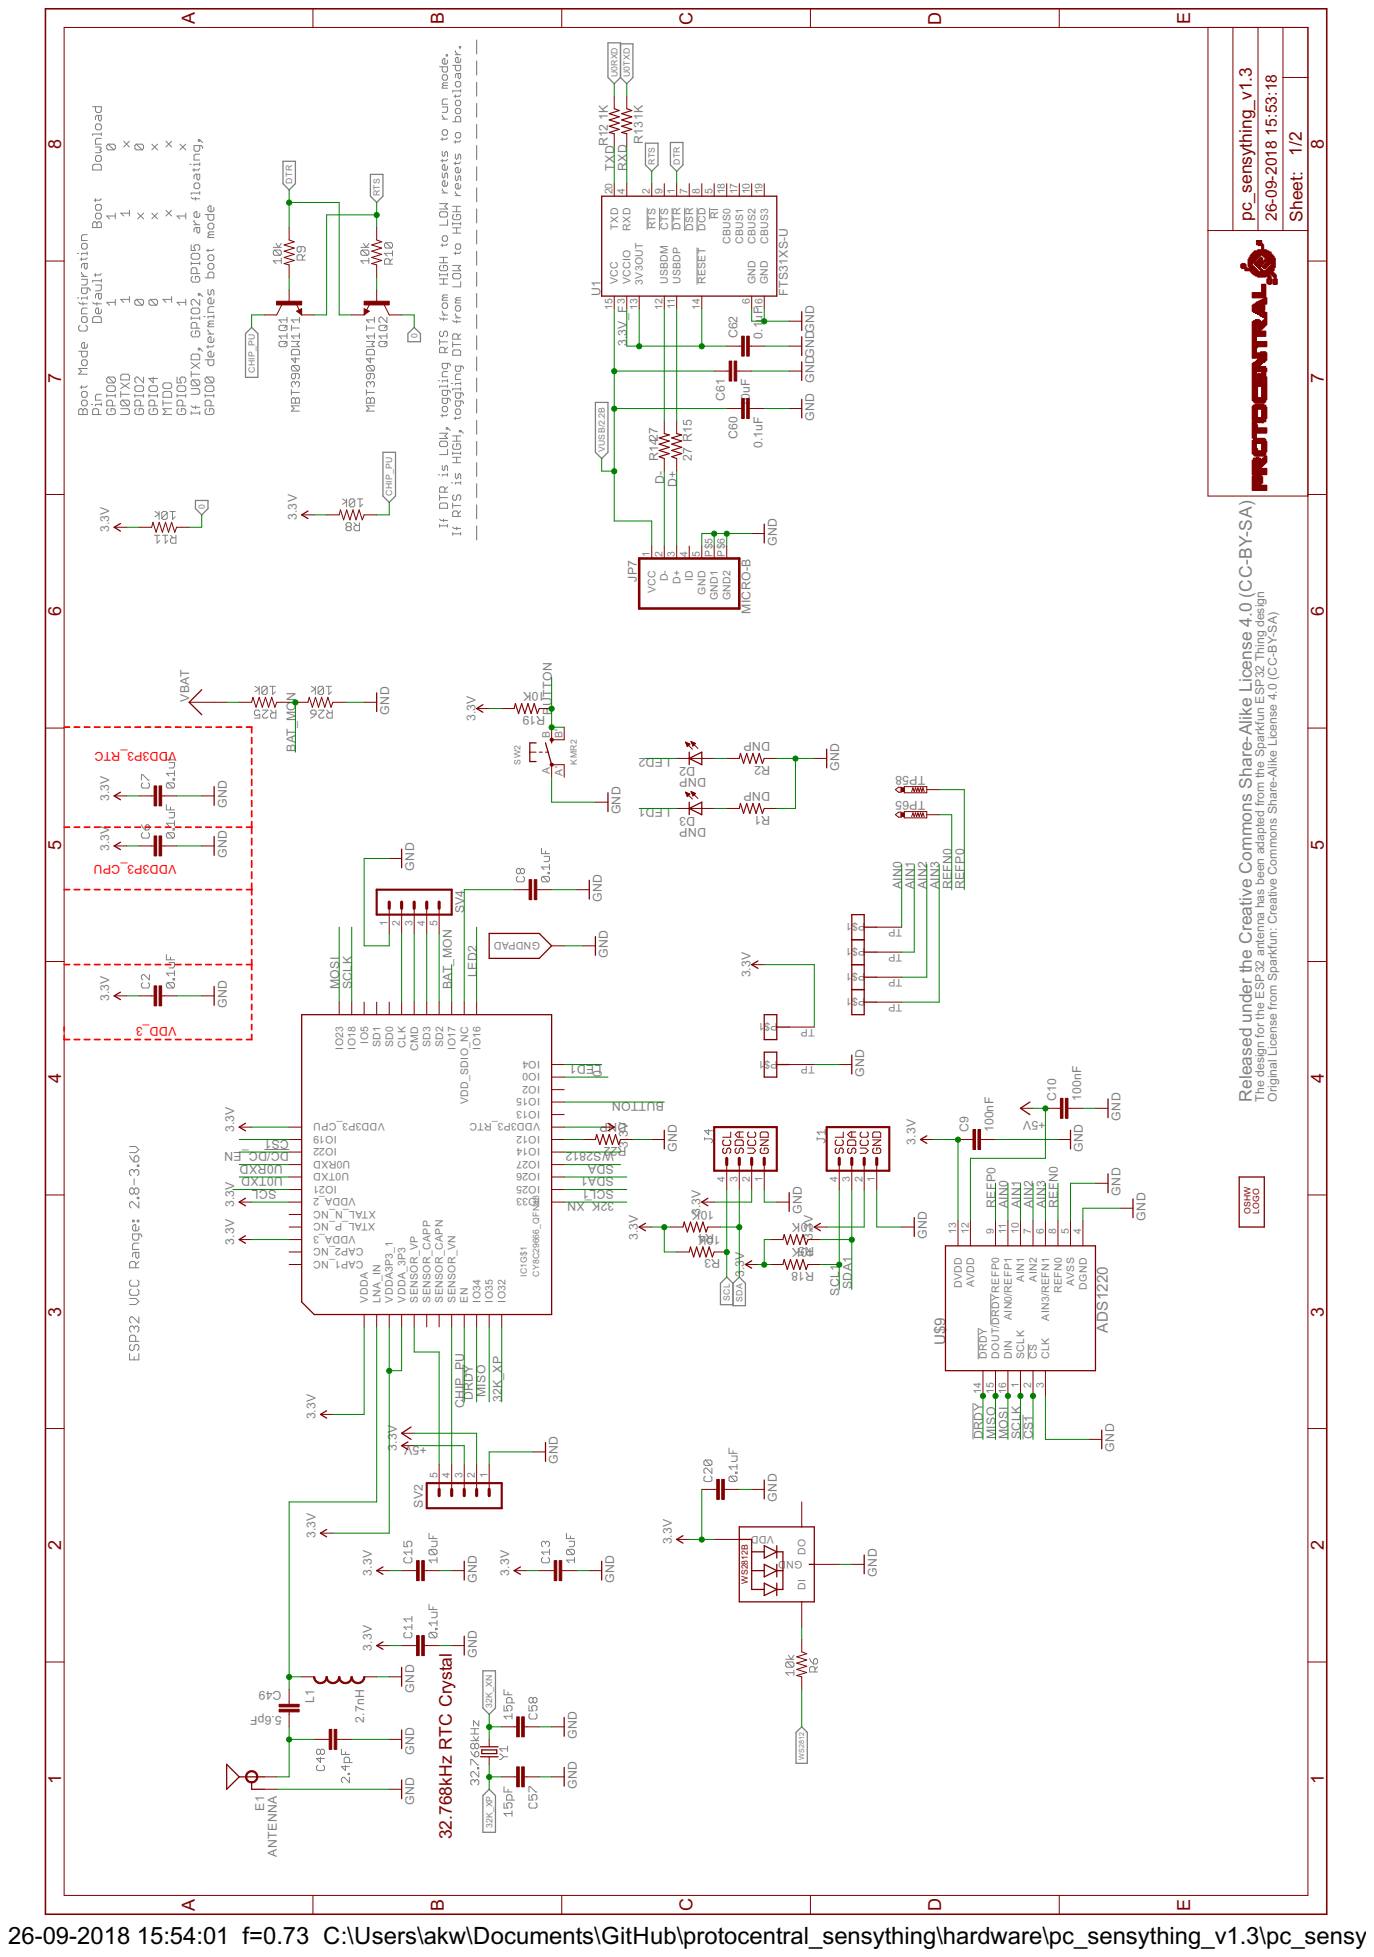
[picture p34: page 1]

0.1uF GND GND GND GND MICRO-B

mons Share-Alike License 4.0 (C

The design for the ESP32 antenna has been adapted from the Sparkfun ESP32 Thing design Original License from Sparkfun: Creative Commons Share-Alike License 4.0 (CC-BY-SA) Released under the Creative Com

26-09-2018 15:54:01 f=0.73 C:\Users\akw\Documents\GitHub\protocentral_sensything\hardware\pc_sensything_v1.3\pc_sensything_v1.3.sch (Sheet: 1/2)

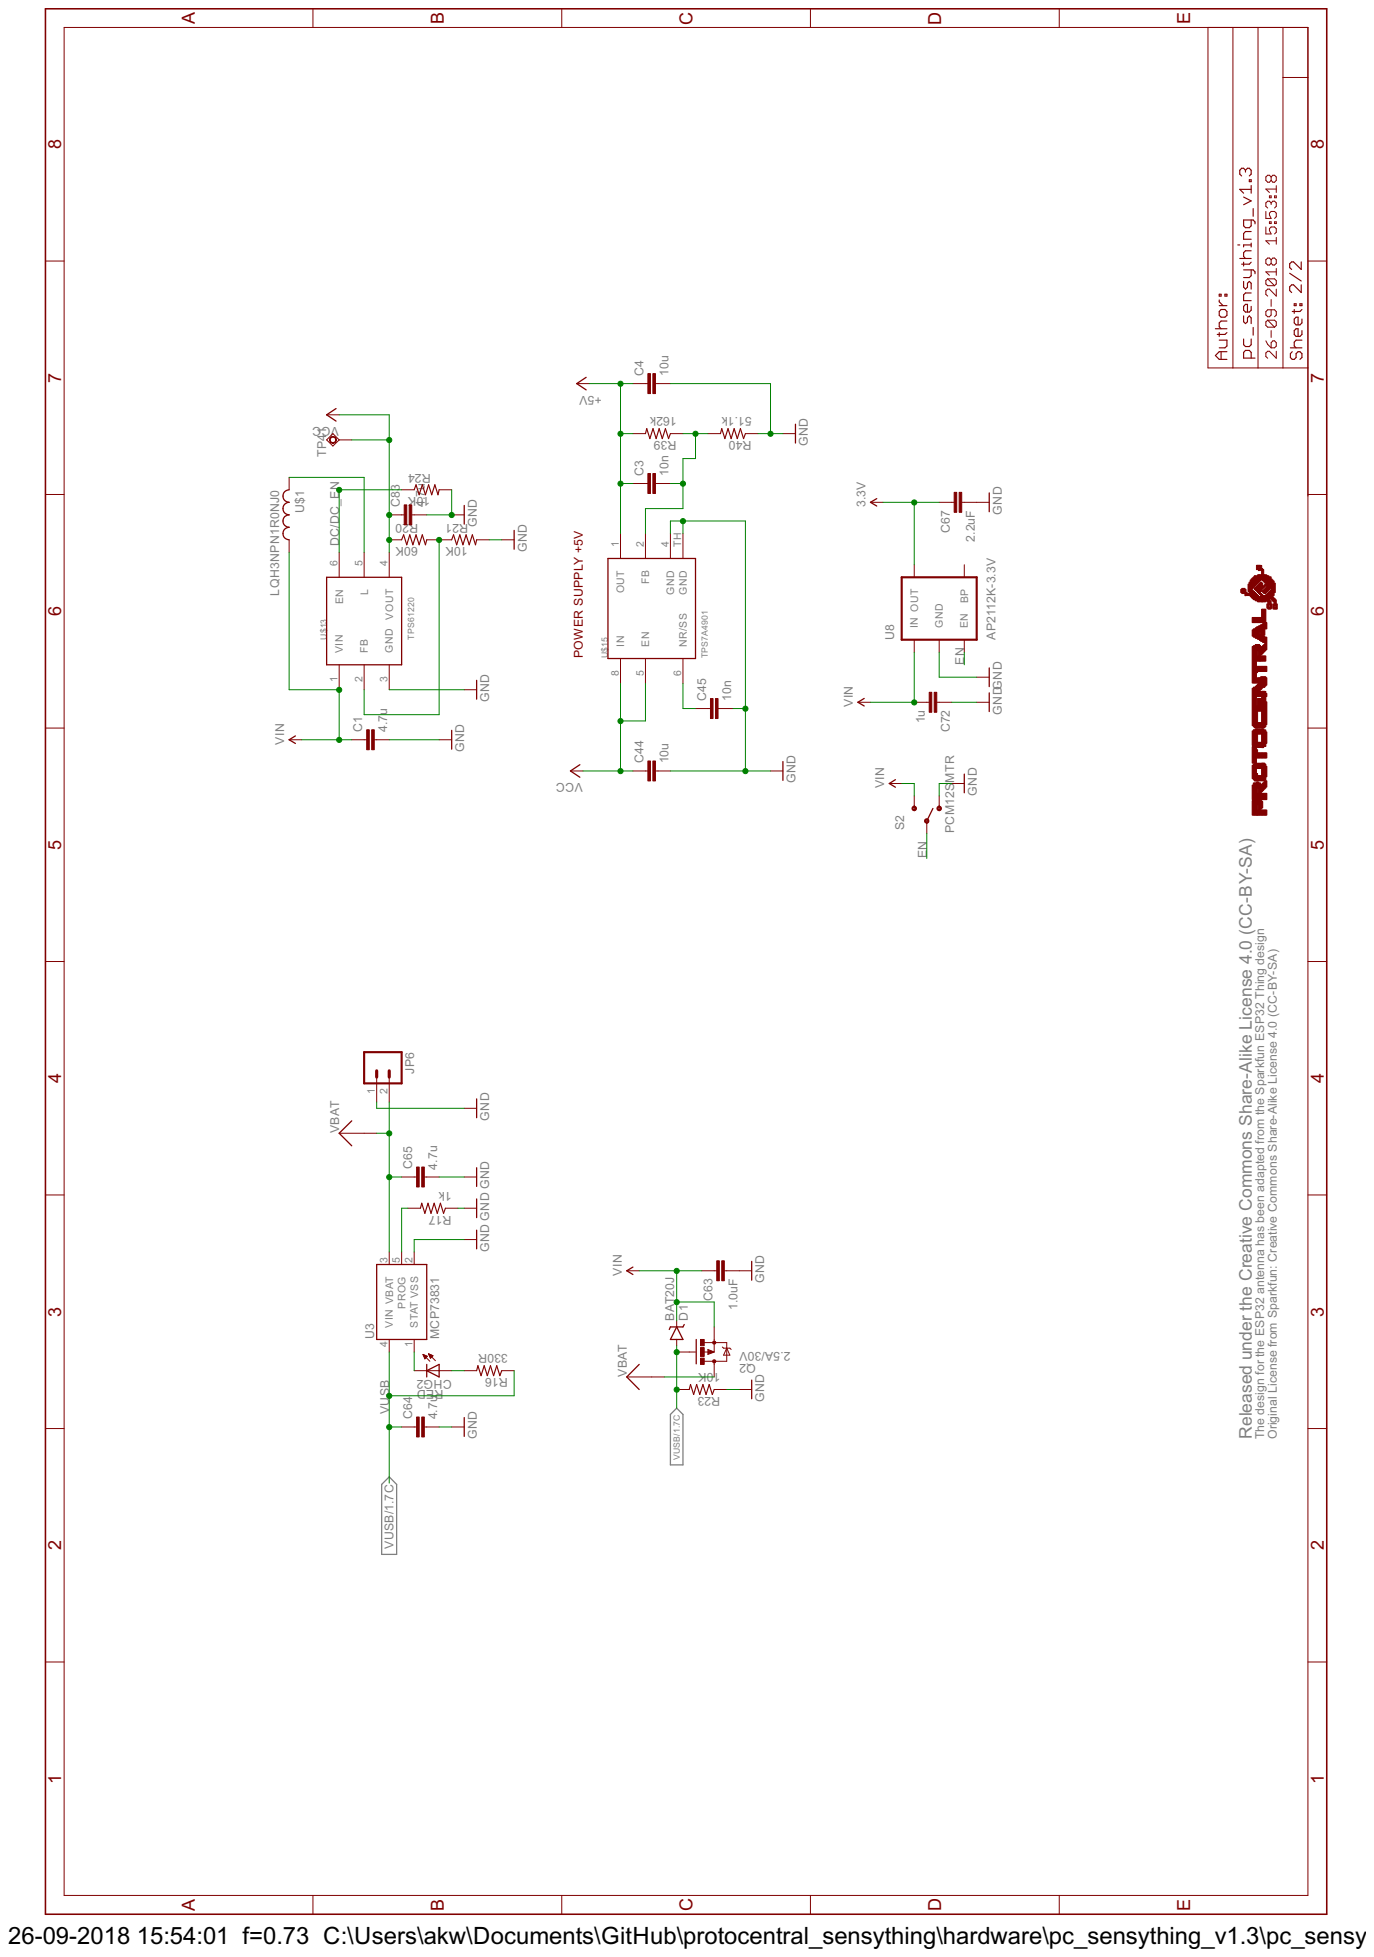
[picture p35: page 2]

mons Share-Alike License 4.0 (C

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

26-09-2018 15:54:01 f=0.73 C:\Users\akw\Documents\GitHub\protocentral_sensything\hardware\pc_sensything_v1.3\pc_sensything_v1.3.sch (Sheet: 2/2)

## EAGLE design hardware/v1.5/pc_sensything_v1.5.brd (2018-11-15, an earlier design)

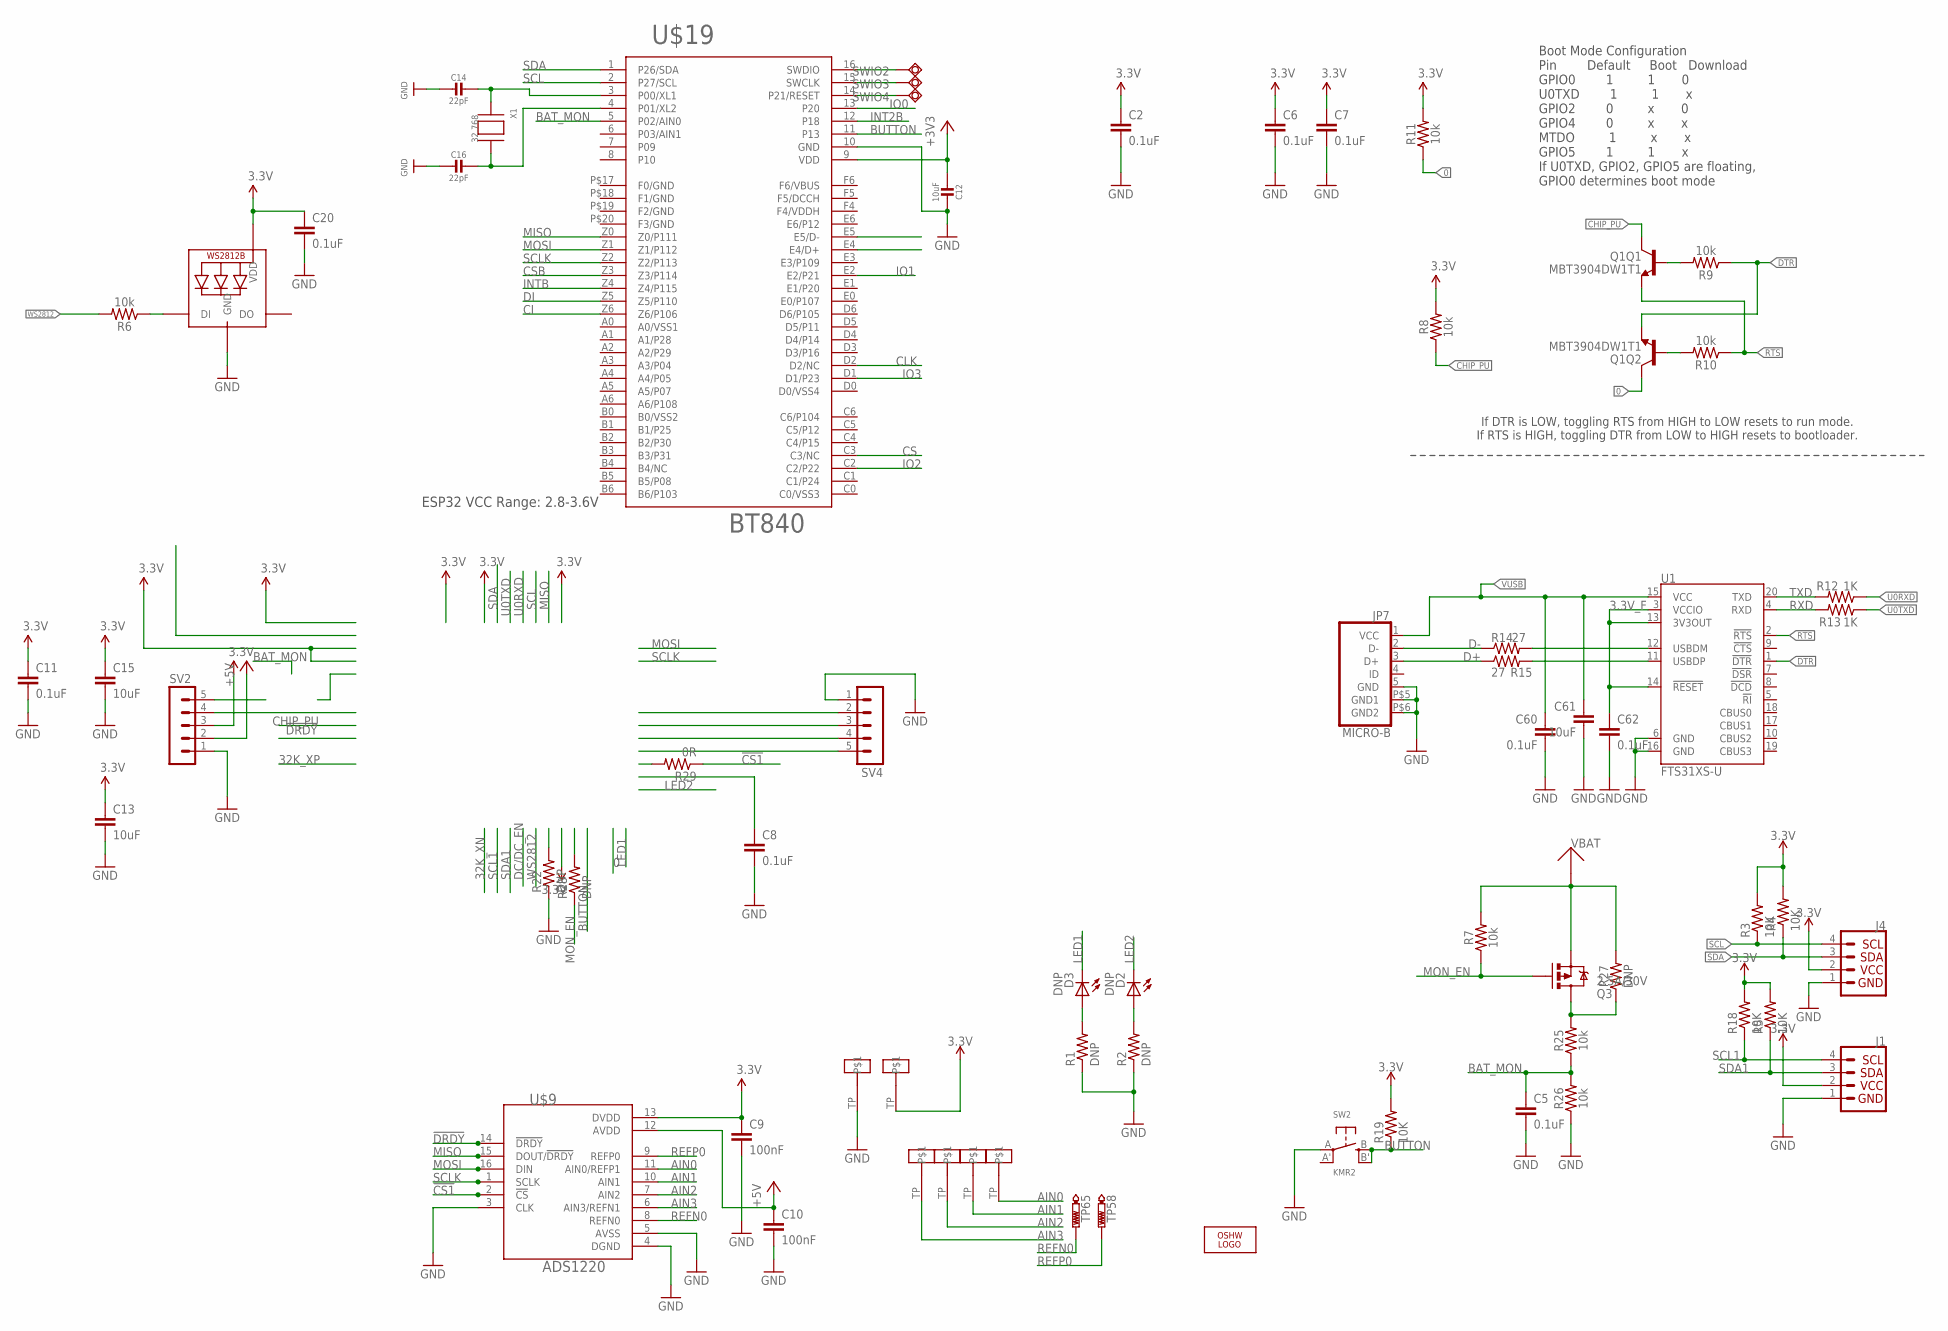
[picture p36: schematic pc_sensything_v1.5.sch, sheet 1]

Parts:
C2, C5, C6, C7, C8, C11: 0.1uF; 0402
C9, C10: 100nF; C0805
C12: 10uF; _0402
C13, C15: 10uF; 0603
C14, C16: 22pF; _0402
C20: 0.1uF; 0603
C60, C62: 0.1uF; C0402
C61: 10uF; C0805
D2, D3: DNP; CHIPLED_0603
J1, J4: QWIIC_CONNECTORJS-1MM; 1X04_1MM_RA
JP7: MICRO-B
LED1: WS2812B5050; WS2812B
LOGO3: OSHW_LOGO_FILLX0200-NT; OSHW_FILLX200_NOTEXT
Q1: MBT3904DW1T1; SC70-6
Q3: 2.5A/30V; SOT23-3
R1, R2, R22, R28: DNP; R0402
R3, R4, R5, R18, R19: 10K; R0402
R6, R7, R8, R9, R10, R11, R25, R26: 10k; 0603
R12, R13: 1K; R0402
R14, R15: 27; R0402
R27: DNP; 0603
R29: 0R; R0402
SV2, SV4: MA05-1
SW2: KMR2; BTN_KMR2_4.6X2.8
SWIO2, SWIO3, SWIO4: TPSQTP11R; TP11R
TP58, TP65: PTR1PAD1-13; P1-13
U1: FTS31XS-U; SSOP20_L
U$3, U$7, U$8, U$11, U$12, U$14: SENSYTHING_CON
U$9: ADS1220; TSSOP-16
U$19: BT840
X1: 32.768; XTAL3215

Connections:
0: Q1.6 (C), R11.1
3.3V: C2.1, C6.1, C7.1, C9.1, C11.1, C13.1, C15.1, C20.1, J1.2, J4.2, LED1.1-VDD (VDD), R3.2, R4.2, R5.2, R8.2, R11.2, R18.2, R19.2, SV2.3, U$9.13 (DVDD), U$14.TP; also elsewhere on the board
3.3V_F: C62.1, U1.3 (VCCIO), U1.13 (3V3OUT), U1.14 (!RESET)
!CS1: R29.1, U$9.2 (!CS)
!DRDY: U$9.14 (!DRDY)
+3V3: C12.1, U$19.9 (VDD)
+5V: C10.1, SV2.2, U$9.12 (AVDD); also elsewhere on the board
AIN0: U$9.11 (AIN0/REFP1), U$11.TP
AIN1: U$8.TP, U$9.10 (AIN1)
AIN2: U$7.TP, U$9.7 (AIN2)
AIN3: U$3.TP, U$9.6 (AIN3/REFN1)
BAT_MON: C5.1, R25.1, R26.2, U$19.5 (P02/AIN0)
BUTTON: R19.1, SW2.B (S), SW2.B' (S1), U$19.11 (P13)
CHIP_PU: Q1.3 (C), R8.1
CI: U$19.Z6 (Z6/P106)
CLK: U$19.D2 (D2/NC)
CS: U$19.C3 (C3/NC)
CSB: U$19.Z3 (Z3/P114)
D+: JP7.3 (D+), R15.1
D-: JP7.2 (D-), R14.1
DI: U$19.Z5 (Z5/P110)
DTR: Q1.1 (E), R9.1, U1.1 (!DTR)
GND: C2.2, C5.2, C6.2, C7.2, C8.2, C9.2, C10.2, C11.2, C12.2, C13.2, C14.2, C15.2, C16.2, C20.2, C60.2, C61.2, C62.2, J1.1, J4.1, JP7.5 (GND), JP7.P$5 (GND1), JP7.P$6 (GND2), LED1.3-GND (GND), R1.1, R2.1, R22.1, R26.1, SV2.1, SV4.1, SW2.A, U1.6 (GND), U1.16 (GND), U$9.3 (CLK), U$9.4 (DGND), U$9.5 (AVSS), U$12.TP, U$19.10 (GND); also elsewhere on the board
INT2B: U$19.12 (P18)
INTB: U$19.Z4 (Z4/P115)
IO0: U$19.13 (P20)
IO1: U$19.E2 (E2/P21)
IO2: U$19.C2 (C2/P22)
IO3: U$19.D1 (D1/P23)
LED1: D3.C
LED2: D2.C
MISO: U$9.15 (DOUT/!DRDY), U$19.Z0 (Z0/P111)
MON_EN: Q3.1 (G), R7.1, R28.1
MOSI: U$9.16 (DIN), U$19.Z1 (Z1/P112)
unnamed: D3.A, R1.2
unnamed: Q1.5 (B), R9.2
unnamed: D2.A, R2.2
unnamed: LED1.4-DIN (DI), R6.1
unnamed: Q1.2 (B), R10.2
unnamed: Q3.3 (D), R25.2, R27.1
unnamed: SWIO2.TP, U$19.16 (SWDIO)
unnamed: SWIO3.TP, U$19.15 (SWCLK)
unnamed: R14.2, U1.12 (USBDM)
unnamed: R15.2, U1.11 (USBDP)
unnamed: SWIO4.TP, U$19.14 (P21/RESET)
unnamed: C14.1, U$19.3 (P00/XL1), X1.P$1
unnamed: C16.1, U$19.4 (P01/XL2), X1.P$2
REFN0: TP65.TP, U$9.8 (REFN0)
REFP0: TP58.TP, U$9.9 (REFP0)
RTS: Q1.4 (E), R10.1, U1.2 (!RTS)
RXD: R13.2, U1.4 (RXD)
SCL: J4.4, R3.1, U$19.2 (P27/SCL)
SCL1: J1.4, R18.1
SCLK: U$9.1 (SCLK), U$19.Z2 (Z2/P113)
SDA: J4.3, R4.1, U$19.1 (P26/SDA)
SDA1: J1.3, R5.1
TXD: R12.2, U1.20 (TXD)
U0RXD: R12.1
U0TXD: R13.1
VBAT: Q3.2 (S), R7.2, R27.2; also elsewhere on the board
VUSB: C60.1, C61.1, JP7.1 (VCC), U1.15 (VCC); also elsewhere on the board
WS2812: R6.2

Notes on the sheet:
Boot Mode Configuration Pin Default Boot Download GPIO0 1 1 0 U0TXD 1 1 x GPIO2 0 x 0 GPIO4 0 x x MTDO 1 x x GPIO5 1 1 x If U0TXD, GPIO2, GPIO5 are floating, GPIO0 determines boot mode
ESP32 VCC Range: 2.8-3.6V
If DTR is LOW, toggling RTS from HIGH to LOW resets to run mode. If RTS is HIGH, toggling DTR from LOW to HIGH resets to bootloader.

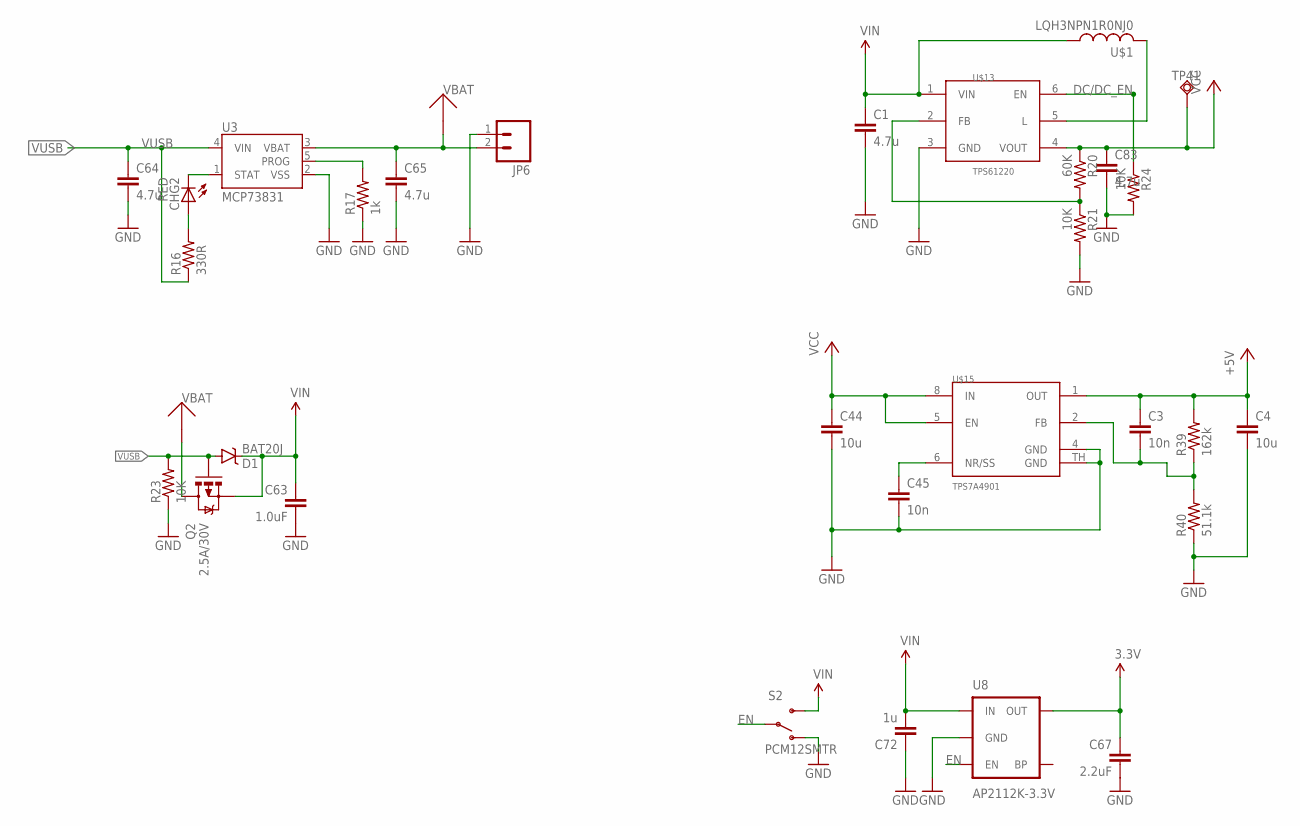
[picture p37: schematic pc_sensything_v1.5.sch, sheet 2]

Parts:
C1, C64, C65, C83: 4.7u; C0805
C3, C45: 10n; C0402
C4, C44: 10u; C0805
C63: 1.0uF; C0402
C67: 2.2uF; C0402
C72: 1u; C0402
CHG2: RED; CHIPLED_0603
D1: BAT20J; SOD-323
JP6: M02-JST-2MM-SMT; JST-2-SMD
Q2: 2.5A/30V; SOT23-3
R16: 330R; R0402
R17: 1k; R0402
R20: 60K; R0805
R21: 10K; R0805
R23, R24: 10K; R0402
R39: 162k; R0805
R40: 51.1k; R0805
S2: PCM12SMTR; SWITCH-SPST-SMD-A
TP41: TPSQB1,27; B1,27
U3: MCP73831; SOT23-5
U8: AP2112K-3.3V; SOT23-5
U$1: LQH3NPN1R0NJ0; LQH3NP
U$13: TPS61220; SC-70-6
U$15: TPS7A4901; S-PDSO-G08

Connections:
3.3V: C67.1, U8.5 (OUT); also elsewhere on the board
+5V: C3.1, C4.1, R39.2, U$15.1 (OUT); also elsewhere on the board
DC/DC_EN: R24.1, U$13.6 (EN)
EN: S2.2, U8.3 (EN)
GND: C1.2, C4.2, C44.2, C45.2, C63.2, C64.2, C65.2, C67.2, C72.1, C83.2, JP6.1, R17.1, R21.2, R23.1, R24.2, R40.1, S2.1 (O), U3.2 (VSS), U8.2 (GND), U$13.3 (GND), U$15.4 (GND), U$15.TH (GND); also elsewhere on the board
unnamed: CHG2.C, U3.1 (STAT)
unnamed: R20.2, R21.1, U$13.2 (FB)
unnamed: C45.1, U$15.6 (NR/SS)
unnamed: C3.2, R39.1, R40.2, U$15.2 (FB)
unnamed: CHG2.A, R16.2
unnamed: R17.2, U3.5 (PROG)
unnamed: U$1.P$2 (2), U$13.5 (L)
VBAT: C65.1, JP6.2, Q2.3 (D), U3.3 (VBAT); also elsewhere on the board
VCC: C44.1, C83.1, R20.1, TP41.TP, U$13.4 (VOUT), U$15.5 (EN), U$15.8 (IN)
VIN: C1.1, C63.1, C72.2, D1.C, Q2.2 (S), S2.3 (S), U8.1 (IN), U$1.P$1 (1), U$13.1 (VIN)
VUSB: C64.1, D1.A, Q2.1 (G), R16.1, R23.2, U3.4 (VIN); also elsewhere on the board

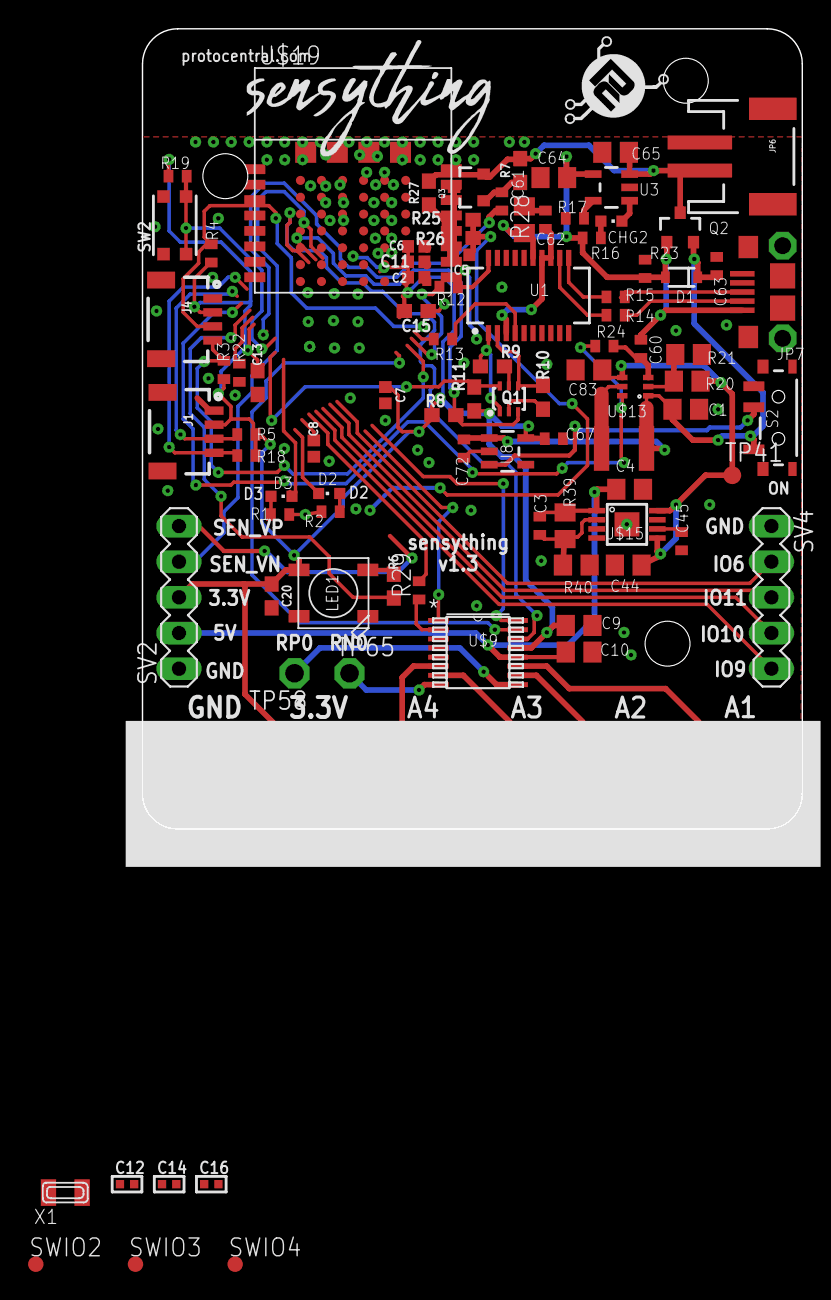
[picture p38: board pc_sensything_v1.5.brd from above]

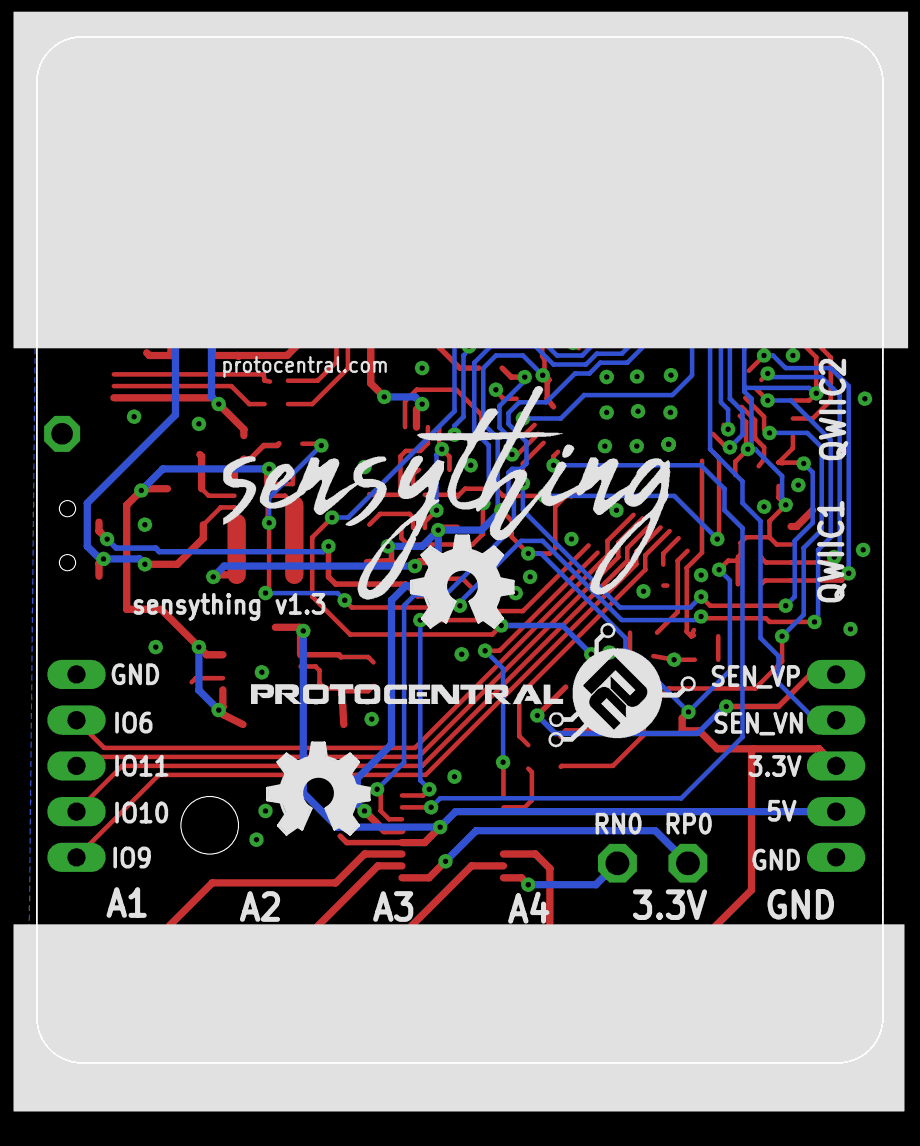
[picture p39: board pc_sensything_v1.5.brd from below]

Board: 4 copper layers, 47.0 x 57.0 mm, 102 parts (4 on the bottom side), 56 nets.

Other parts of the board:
LOGO2: OSHW_LOGO_FILLX0200-NT; OSHW_FILLX200_NOTEXT
U$2: SENSYTHING
U$4: SENSYTHING_SMALL
U$6: LOGO-PROTY
U$26: PROTY_LOGO_WITH_TEXT; PROTY_WITH_TEXT@1

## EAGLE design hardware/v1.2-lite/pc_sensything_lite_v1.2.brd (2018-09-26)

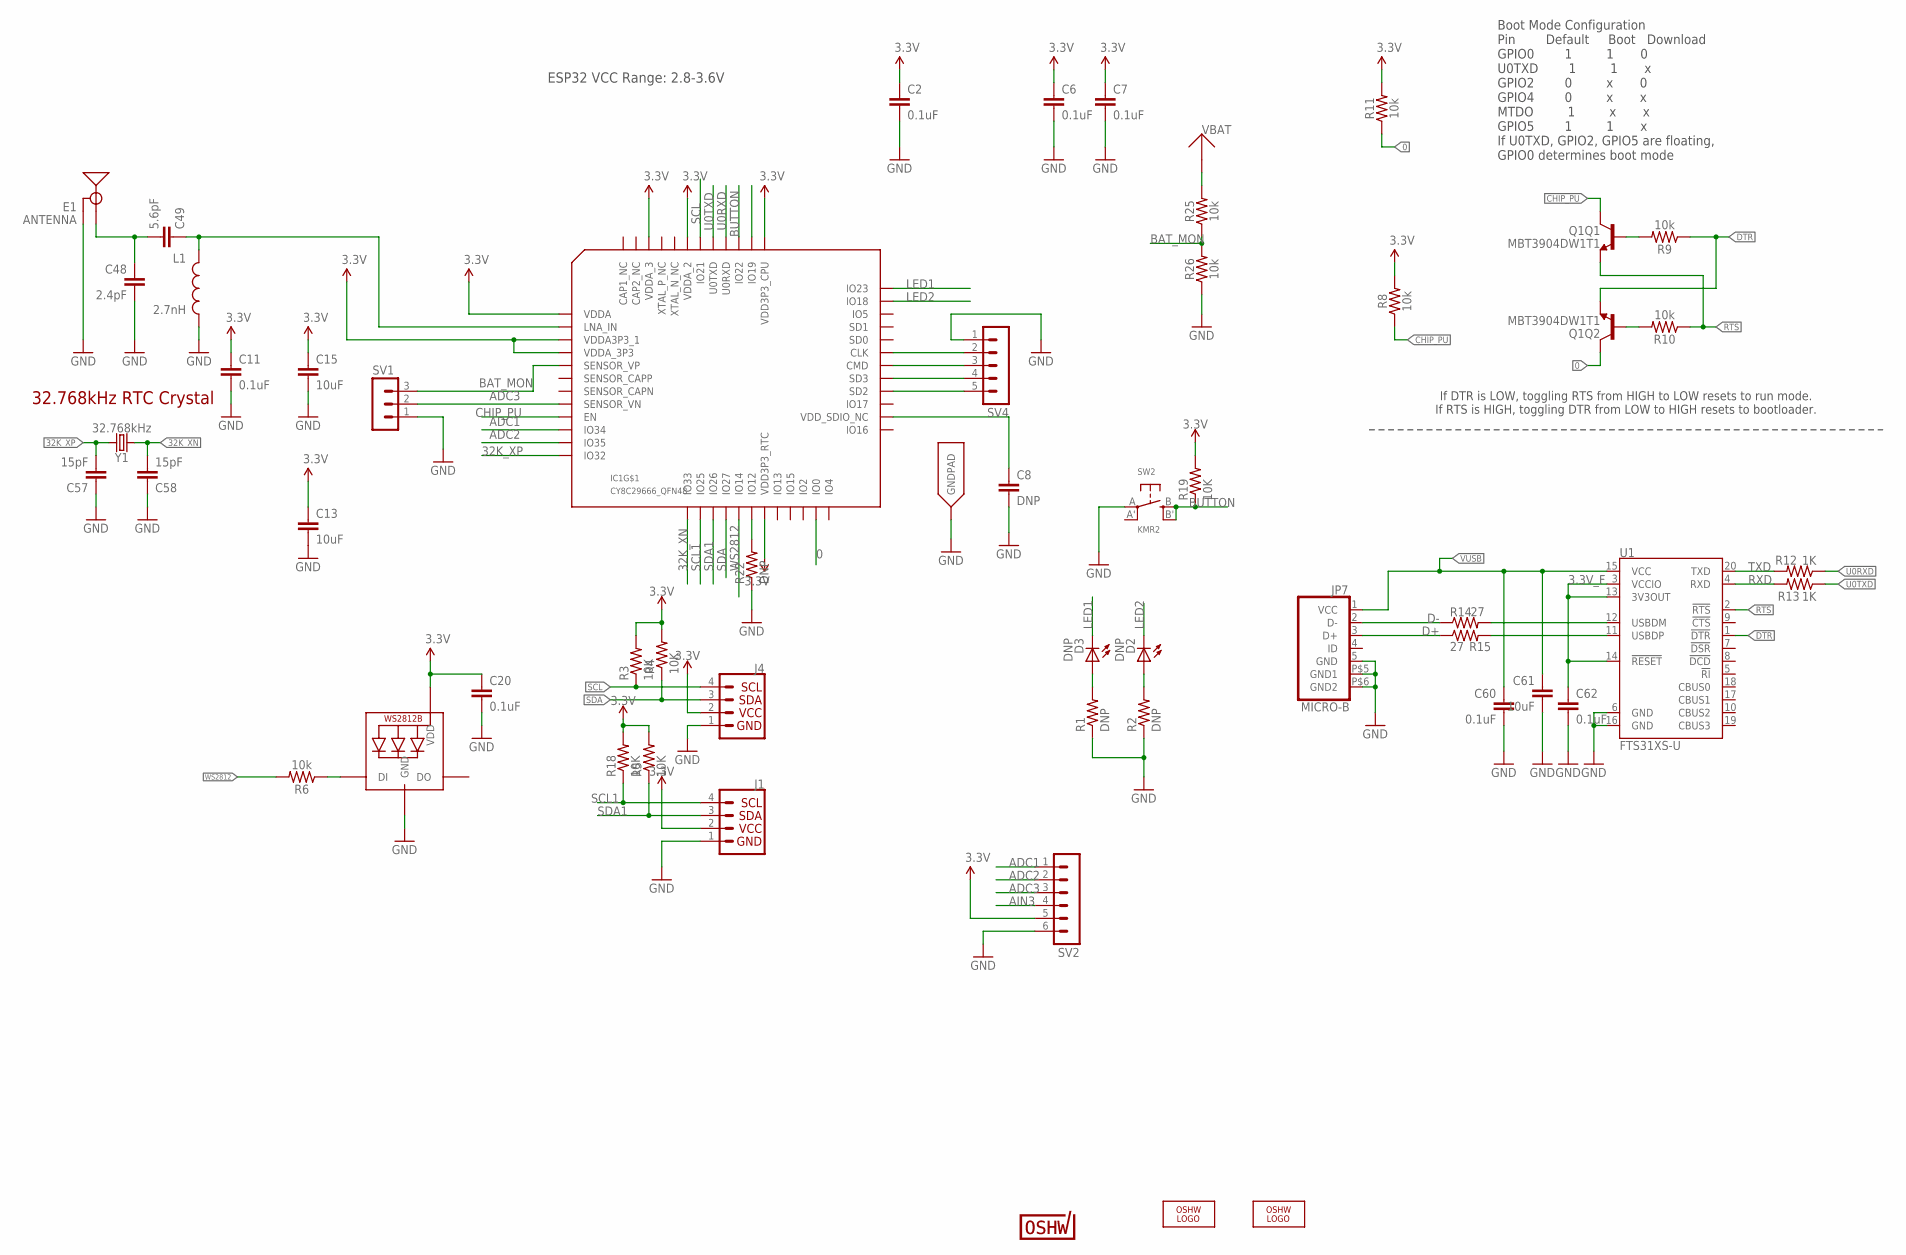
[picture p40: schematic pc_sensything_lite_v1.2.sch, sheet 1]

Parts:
C2, C6, C7, C11: 0.1uF; 0402
C8: DNP; 0603
C13: 10uF; C0402
C15: 10uF; 0603
C20: 0.1uF; 0603
C48: 2.4pF; 0603
C49: 5.6pF; 0603
C57, C58: 15pF; 0603
C60, C62: 0.1uF; C0402
C61: 10uF; C0805
D2, D3: DNP; CHIPLED_0603
E1: ANTENNA; TRACE_ANTENNA_2.4GHZ_25.7MM_TUNED
IC1: CY8C29666_QFN48; QFN48
J1, J4: QWIIC_CONNECTORJS-1MM; 1X04_1MM_RA
JP7: MICRO-B
L1: 2.7nH; 0603
LED1: WS2812B5050; WS2812B
LOGO1, LOGO3: OSHW_LOGO_FILLX0200-NT; OSHW_FILLX200_NOTEXT
Q1: MBT3904DW1T1; SC70-6
R1, R2, R22: DNP; R0402
R3, R4, R5, R18, R19: 10K; R0402
R6, R8, R9, R10, R11, R25, R26: 10k; 0603
R12, R13: 1K; R0402
R14, R15: 27; R0402
SV1: MA03-1
SV2: MA06-1
SV4: MA05-1
SW2: KMR2; BTN_KMR2_4.6X2.8
U1: FTS31XS-U; SSOP20_L
U$22: CERT-SMALL; CERT-SMALL-SILK
Y1: 32.768kHz; CRYSTAL-SMD-3.2X1.5MM

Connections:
0: IC1.23 (IO0), Q1.6 (C), R11.1
3.3V: C2.1, C6.1, C7.1, C11.1, C13.1, C15.1, C20.1, IC1.1 (VDDA), IC1.3 (VDDA3P3_1), IC1.4 (VDDA_3P3), IC1.19 (VDD3P3_RTC), IC1.37 (VDD3P3_CPU), IC1.43 (VDDA_2), IC1.46 (VDDA_3), J1.2, J4.2, LED1.1-VDD (VDD), R3.2, R4.2, R5.2, R8.2, R11.2, R18.2, R19.2, SV2.5; also elsewhere on the board
3.3V_F: C62.1, U1.3 (VCCIO), U1.13 (3V3OUT), U1.14 (!RESET)
32K_XN: C58.2, IC1.13 (IO33), Y1.P$2 (2)
32K_XP: C57.2, IC1.12 (IO32), Y1.P$1 (1)
ADC1: IC1.10 (IO34), SV2.1
ADC2: IC1.11 (IO35), SV2.2
ADC3: IC1.8 (SENSOR_VN), SV1.2, SV2.3
AIN3: SV2.4
BAT_MON: IC1.5 (SENSOR_VP), R25.1, R26.2, SV1.3
BUTTON: IC1.39 (IO22), R19.1, SW2.B (S), SW2.B' (S1)
CHIP_PU: IC1.9 (EN), Q1.3 (C), R8.1
D+: JP7.3 (D+), R15.1
D-: JP7.2 (D-), R14.1
DTR: Q1.1 (E), R9.1, U1.1 (!DTR)
GND: C2.2, C6.2, C7.2, C8.2, C11.2, C13.2, C15.2, C20.2, C48.2, C57.1, C58.1, C60.2, C61.2, C62.2, E1.GND, E1.GND2 (GND), IC1.EXP (GNDPAD), J1.1, J4.1, JP7.5 (GND), JP7.P$5 (GND1), JP7.P$6 (GND2), L1.2, LED1.3-GND (GND), R1.1, R2.1, R22.1, R26.1, SV1.1, SV2.6, SV4.1, SW2.A, U1.6 (GND), U1.16 (GND); also elsewhere on the board
LED1: D3.C, IC1.36 (IO23)
LED2: D2.C, IC1.35 (IO18)
LNA_IN: C49.1, IC1.2 (LNA_IN), L1.1
unnamed: C8.1, IC1.26 (VDD_SDIO_NC)
unnamed: IC1.18 (IO12), R22.2
unnamed: D3.A, R1.2
unnamed: Q1.5 (B), R9.2
unnamed: D2.A, R2.2
unnamed: LED1.4-DIN (DI), R6.1
unnamed: Q1.2 (B), R10.2
unnamed: IC1.28 (SD2), SV4.5
unnamed: IC1.29 (SD3), SV4.4
unnamed: IC1.30 (CMD), SV4.3
unnamed: IC1.31 (CLK), SV4.2
unnamed: R14.2, U1.12 (USBDM)
unnamed: R15.2, U1.11 (USBDP)
RTS: Q1.4 (E), R10.1, U1.2 (!RTS)
RXD: R13.2, U1.4 (RXD)
SCL: IC1.42 (IO21), J4.4, R3.1
SCL1: IC1.14 (IO25), J1.4, R18.1
SDA: IC1.16 (IO27), J4.3, R4.1
SDA1: IC1.15 (IO26), J1.3, R5.1
SENSOR_CAPN: IC1.7 (SENSOR_CAPN)
TRACE_ANT2: C48.1, C49.2, E1.ANT (SIGNAL)
TXD: R12.2, U1.20 (TXD)
U0RXD: IC1.40 (U0RXD), R12.1
U0TXD: IC1.41 (U0TXD), R13.1
VBAT: R25.2; also elsewhere on the board
VUSB: C60.1, C61.1, JP7.1 (VCC), U1.15 (VCC); also elsewhere on the board
WS2812: IC1.17 (IO14), R6.2

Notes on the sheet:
Boot Mode Configuration Pin Default Boot Download GPIO0 1 1 0 U0TXD 1 1 x GPIO2 0 x 0 GPIO4 0 x x MTDO 1 x x GPIO5 1 1 x If U0TXD, GPIO2, GPIO5 are floating, GPIO0 determines boot mode
32.768kHz RTC Crystal
ESP32 VCC Range: 2.8-3.6V
If DTR is LOW, toggling RTS from HIGH to LOW resets to run mode. If RTS is HIGH, toggling DTR from LOW to HIGH resets to bootloader.

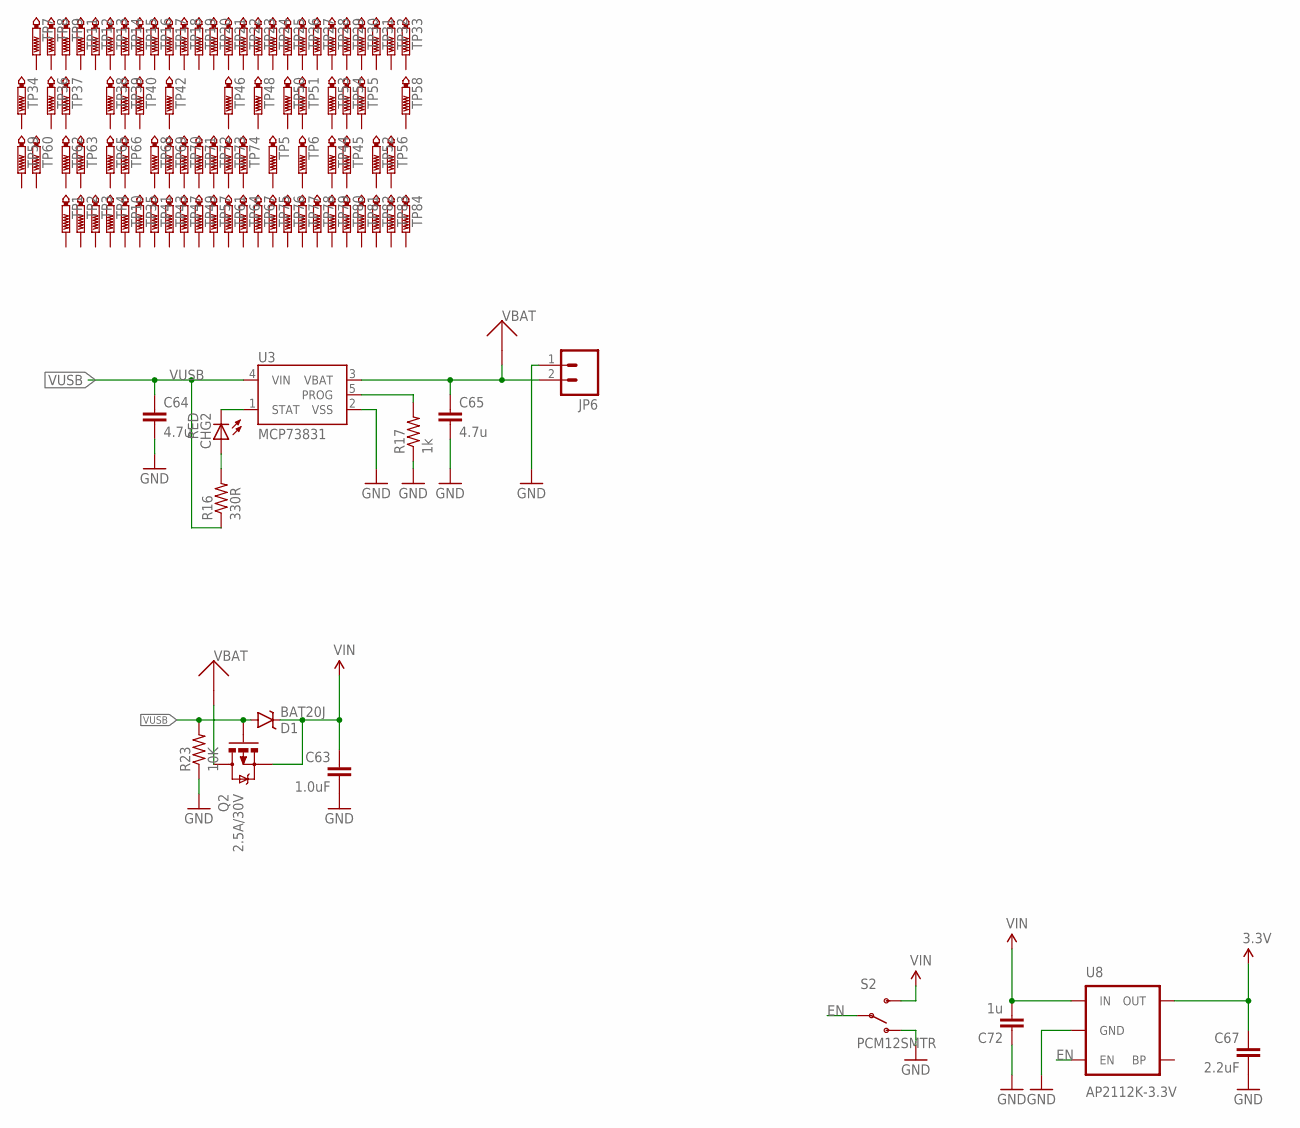
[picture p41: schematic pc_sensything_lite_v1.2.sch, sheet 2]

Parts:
C63: 1.0uF; C0402
C64, C65: 4.7u; C0805
C67: 2.2uF; C0402
C72: 1u; C0402
CHG2: RED; CHIPLED_0603
D1: BAT20J; SOD-323
JP6: M02-JST-2MM-SMT; JST-2-SMD
Q2: 2.5A/30V; SOT23-3
R16: 330R; R0402
R17: 1k; R0402
R23: 10K; R0402
S2: PCM12SMTR; SWITCH-SPST-SMD-A
TP1, TP2, TP3, TP4, TP5, TP6, TP7, TP8, TP9, TP10, TP11, TP12, TP13, TP14, TP15, TP16, TP17, TP18, TP19, TP20, TP21, TP22, TP23, TP24, TP25, TP26, TP27, TP28, TP29, TP30, TP31, TP32, TP33, TP34, TP35, TP36, TP37, TP38, TP39, TP40, TP41, TP42, TP43, TP44, TP45, TP46, TP47, TP48, TP49, TP50, TP51, TP52, TP53, TP54, TP55, TP56, TP57, TP58, TP59, TP60, TP61, TP62, TP63, TP64, TP65, TP66, TP67, TP68, TP69, TP70, TP71, TP72, TP73, TP74, TP75, TP76, TP77, TP78, TP79, TP80, TP81, TP82, TP83, TP84: PTR1PAD1-13; P1-13
U3: MCP73831; SOT23-5
U8: AP2112K-3.3V; SOT23-5

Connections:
3.3V: C67.1, U8.5 (OUT); also elsewhere on the board
EN: S2.2, U8.3 (EN)
GND: C63.2, C64.2, C65.2, C67.2, C72.1, JP6.1, R17.1, R23.1, S2.1 (O), U3.2 (VSS), U8.2 (GND); also elsewhere on the board
unnamed: CHG2.C, U3.1 (STAT)
unnamed: CHG2.A, R16.2
unnamed: R17.2, U3.5 (PROG)
VBAT: C65.1, JP6.2, Q2.3 (D), U3.3 (VBAT); also elsewhere on the board
VIN: C63.1, C72.2, D1.C, Q2.2 (S), S2.3 (S), U8.1 (IN)
VUSB: C64.1, D1.A, Q2.1 (G), R16.1, R23.2, U3.4 (VIN); also elsewhere on the board

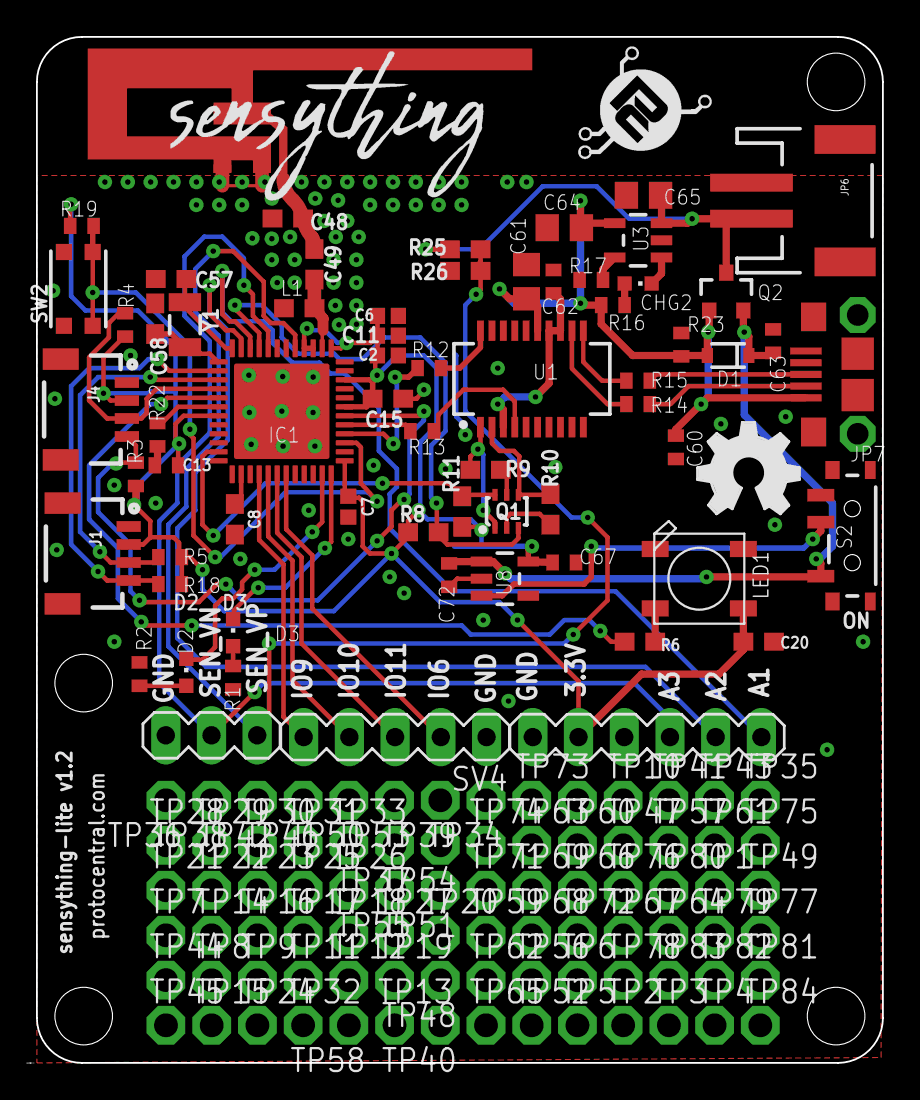
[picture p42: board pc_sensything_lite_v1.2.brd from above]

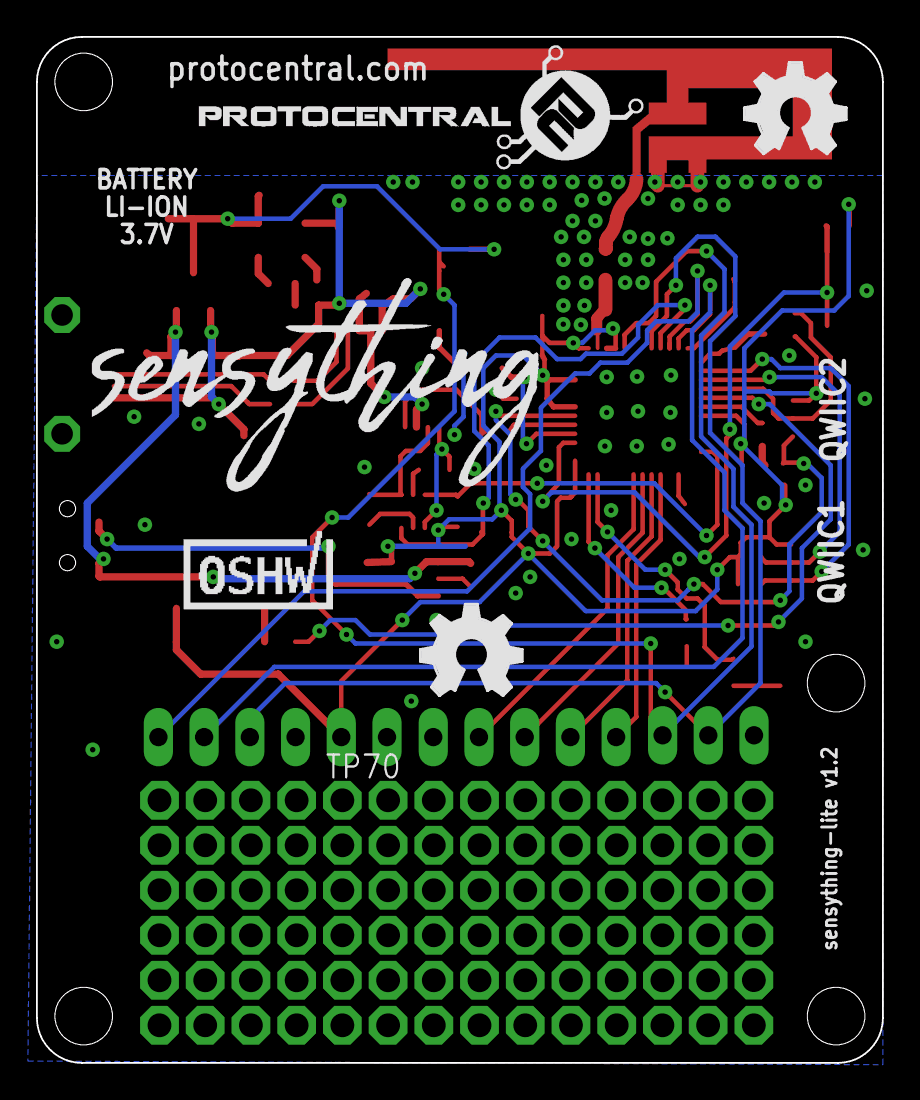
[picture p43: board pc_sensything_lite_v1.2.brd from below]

Board: 4 copper layers, 47.0 x 57.0 mm, 157 parts (6 on the bottom side), 49 nets.

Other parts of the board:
LOGO2: OSHW_LOGO_FILLX0200-NT; OSHW_FILLX200_NOTEXT
U$2: SENSYTHING
U$4: SENSYTHING_SMALL
U$6: LOGO-PROTY
U$26: PROTY_LOGO_WITH_TEXT; PROTY_WITH_TEXT@1

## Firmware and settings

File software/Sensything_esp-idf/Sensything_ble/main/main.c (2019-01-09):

#include <stdio.h>
#include <stdlib.h>
#include <string.h>
#include <sys/socket.h>

#include "freertos/FreeRTOS.h"
#include "freertos/task.h"
#include "freertos/event_groups.h"
#include "esp_wifi.h"
#include "esp_system.h"
#include "esp_event.h"
#include "esp_event_loop.h"
#include "nvs_flash.h"
#include "driver/gpio.h"
#include "driver/spi_master.h"
#include "driver/ledc.h"
//#include "bt.h"				//use this for esp-idf versions below 3.0  else use esp_bt.h
#include "esp_bt.h"
#include "driver/i2c.h"
#include "driver/uart.h"
#include "driver/sdmmc_host.h"

#include "esp_log.h"
#include "sensything_ble.h"
#include "sensything_ads1220.h"
#include "ws2812.h"
#include "sensything_adc.h"
#include "sensything_qwiic.h"

#define TAG "Sensything:"
#define SENSYTHING_MDNS_ENABLED    FALSE
#define SENSYTHING_MDNS_NAME       "heartypatch"
#define BUF_SIZE  1000


extern xSemaphoreHandle print_mux;
char uart_data[50];
const int uart_num = UART_NUM_1;
uint8_t* db;

static EventGroupHandle_t wifi_event_group;
const int CONNECTED_BIT_SENSYTHING = BIT0;

uint8_t* db;
unsigned int global_heartRate ; 


static esp_err_t event_handler(void *ctx, system_event_t *event)
{
  switch(event->event_id) {
  case SYSTEM_EVENT_STA_START:
  esp_wifi_connect();
  break;
  case SYSTEM_EVENT_STA_GOT_IP:
  xEventGroupSetBits(wifi_event_group, CONNECTED_BIT_SENSYTHING);
  break;
  case SYSTEM_EVENT_STA_DISCONNECTED:
  esp_wifi_connect();
  xEventGroupClearBits(wifi_event_group, CONNECTED_BIT_SENSYTHING);
  break;
  default:
  break;
  }
  return ESP_OK;
}

void sensything_wifi_init(void)
{
  tcpip_adapter_init();
  wifi_event_group = xEventGroupCreate();
  ESP_ERROR_CHECK( esp_event_loop_init(event_handler, NULL) );
  wifi_init_config_t cfg = WIFI_INIT_CONFIG_DEFAULT();
  ESP_ERROR_CHECK( esp_wifi_init(&cfg) );
  ESP_ERROR_CHECK( esp_wifi_set_storage(WIFI_STORAGE_RAM) );
  wifi_config_t wifi_config = {
  .sta = {
  .ssid = CONFIG_WIFI_SSID,
  .password = CONFIG_WIFI_PASSWORD,
  },
  };
  ESP_LOGI(TAG, "Setting WiFi configuration SSID %s...", wifi_config.sta.ssid);
  ESP_ERROR_CHECK( esp_wifi_set_mode(WIFI_MODE_STA) );
  ESP_ERROR_CHECK( esp_wifi_set_config(WIFI_IF_STA, &wifi_config) );
  ESP_ERROR_CHECK( esp_wifi_start() );
}

void app_main(void)
{

    // Initialize NVS.
  esp_err_t ret;
  ret = nvs_flash_init();
  ESP_ERROR_CHECK( ret );

  sensything_ads1220start();
	vTaskDelay(2000/ portTICK_PERIOD_MS);		//give sometime for max to settle

#ifdef CONFIG_RGB_LED_ENABLE
  ws2812_init(WS2812_PIN);
  vTaskDelay(200/ portTICK_PERIOD_MS);
#endif

  sensything_adc_start();
  vTaskDelay(200/ portTICK_PERIOD_MS);

  init_qwiic();
  vTaskDelay(200/ portTICK_PERIOD_MS);

#ifdef CONFIG_BLE_MODE_ENABLE
  sensything_ble_init();		
#endif

#ifdef CONFIG_WIFIMODE_ENABLE					//configure the ssid/password under makemenuconfig/heartypatch configuration. 
  sensything_wifi_init();
  xEventGroupWaitBits(wifi_event_group, CONNECTED_BIT_SENSYTHING,false, true, portMAX_DELAY);
  /*as of now, functionalities based on wifi is not added*/
#endif

}

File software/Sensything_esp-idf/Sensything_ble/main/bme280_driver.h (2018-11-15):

/** \mainpage
*
****************************************************************************
* Copyright (C) 2015 - 2016 Bosch Sensortec GmbH
*
* File : bme280.h
*
* Date : 2016/07/04
*
* Revision : 2.0.5(Pressure and Temperature compensation code revision is 1.1
*               and Humidity compensation code revision is 1.0)
*
* Usage: Sensor Driver for BME280 sensor
*
****************************************************************************
*
* \section License
*
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
*   Redistributions of source code must retain the above copyright
*   notice, this list of conditions and the following disclaimer.
*
*   Redistributions in binary form must reproduce the above copyright
*   notice, this list of conditions and the following disclaimer in the
*   documentation and/or other materials provided with the distribution.
*
*   Neither the name of the copyright holder nor the names of the
*   contributors may be used to endorse or promote products derived from
*   this software without specific prior written permission.
*
* THIS SOFTWARE IS PROVIDED BY THE COPYRIGHT HOLDERS AND
* CONTRIBUTORS "AS IS" AND ANY EXPRESS OR
* IMPLIED WARRANTIES, INCLUDING, BUT NOT LIMITED TO, THE IMPLIED
* WARRANTIES OF MERCHANTABILITY AND FITNESS FOR A PARTICULAR PURPOSE ARE
* DISCLAIMED. IN NO EVENT SHALL COPYRIGHT HOLDER
* OR CONTRIBUTORS BE LIABLE FOR ANY
* DIRECT, INDIRECT, INCIDENTAL, SPECIAL, EXEMPLARY,
* OR CONSEQUENTIAL DAMAGES(INCLUDING, BUT NOT LIMITED TO,
* PROCUREMENT OF SUBSTITUTE GOODS OR SERVICES;
* LOSS OF USE, DATA, OR PROFITS; OR BUSINESS INTERRUPTION)
* HOWEVER CAUSED AND ON ANY THEORY OF LIABILITY,
* WHETHER IN CONTRACT, STRICT LIABILITY, OR TORT
* (INCLUDING NEGLIGENCE OR OTHERWISE) ARISING IN
* ANY WAY OUT OF THE USE OF THIS
* SOFTWARE, EVEN IF ADVISED OF THE POSSIBILITY OF SUCH DAMAGE
*
* The information provided is believed to be accurate and reliable.
* The copyright holder assumes no responsibility
* for the consequences of use
* of such information nor for any infringement of patents or
* other rights of third parties which may result from its use.
* No license is granted by implication or otherwise under any patent or
* patent rights of the copyright holder.
**************************************************************************/
/*! \file bme280.h
    \brief BME280 Sensor Driver Support Header File */
#ifndef __BME280_H__
#define __BME280_H__


/*!
* @brief The following definition uses for define the data types
*
* @note While porting the API please consider the following
* @note Please check the version of C standard
* @note Are you using Linux platform
*/

/*!
* @brief For the Linux platform support
* Please use the types.h for your data types definitions
*/
#ifdef	__KERNEL__

#include <linux/types.h>
#include <linux/math64.h>
#define BME280_64BITSUPPORT_PRESENT
/* singed integer type*/
typedef	int8_t s8;/**< used for signed 8bit */
typedef	int16_t s16;/**< used for signed 16bit */
typedef	int32_t s32;/**< used for signed 32bit */
typedef	int64_t s64;/**< used for signed 64bit */

typedef	u_int8_t u8;/**< used for unsigned 8bit */
typedef	u_int16_t u16;/**< used for unsigned 16bit */
typedef	u_int32_t u32;/**< used for unsigned 32bit */
typedef	u_int64_t u64;/**< used for unsigned 64bit */



#else /* ! __KERNEL__ */
/**********************************************************
* These definition uses for define the C
* standard version data types
***********************************************************/
# if defined(__STDC_VERSION__)

/************************************************
 * compiler is C11 C standard
************************************************/
#if (__STDC_VERSION__ == 201112L)

/************************************************/
#include <stdint.h>
/************************************************/

/*unsigned integer types*/
typedef	uint8_t u8;/**< used for unsigned 8bit */
typedef	uint16_t u16;/**< used for unsigned 16bit */
typedef	uint32_t u32;/**< used for unsigned 32bit */
typedef	uint64_t u64;/**< used for unsigned 64bit */

/*signed integer types*/
typedef	int8_t s8;/**< used for signed 8bit */
typedef	int16_t s16;/**< used for signed 16bit */
typedef	int32_t s32;/**< used for signed 32bit */
typedef	int64_t s64;/**< used for signed 64bit */
#define BME280_64BITSUPPORT_PRESENT
/************************************************
 * compiler is C99 C standard
************************************************/

#elif (__STDC_VERSION__ == 199901L)

/* stdint.h is a C99 supported c library.
which is used to fixed the integer size*/
/************************************************/
#include <stdint.h>
/************************************************/

/*unsigned integer types*/
typedef	uint8_t u8;/**< used for unsigned 8bit */
typedef	uint16_t u16;/**< used for unsigned 16bit */
typedef	uint32_t u32;/**< used for unsigned 32bit */
typedef	uint64_t u64;/**< used for unsigned 64bit */

/*signed integer types*/
typedef int8_t s8;/**< used for signed 8bit */
typedef	int16_t s16;/**< used for signed 16bit */
typedef	int32_t s32;/**< used for signed 32bit */
typedef	int64_t s64;/**< used for signed 64bit */
#define BME280_64BITSUPPORT_PRESENT
/************************************************
 * compiler is C89 or other C standard
************************************************/

#else /*  !defined(__STDC_VERSION__) */
/*!
* @brief By default it is defined as 32 bit machine configuration
*	define your data types based on your
*	machine/compiler/controller configuration
*/
#define  MACHINE_32_BIT

/*! @brief
 *	If your machine support 16 bit
 *	define the MACHINE_16_BIT
 */
#ifdef MACHINE_16_BIT
#include <limits.h>
/*signed integer types*/
typedef	signed char  s8;/**< used for signed 8bit */
typedef	signed short int s16;/**< used for signed 16bit */
typedef	signed long int s32;/**< used for signed 32bit */

#if defined(LONG_MAX) && LONG_MAX == 0x7fffffffffffffffL
typedef long int s64;/**< used for signed 64bit */
typedef unsigned long int u64;/**< used for unsigned 64bit */
#define BME280_64BITSUPPORT_PRESENT
#elif defined(LLONG_MAX) && (LLONG_MAX == 0x7fffffffffffffffLL)
typedef long long int s64;/**< used for signed 64bit */
typedef unsigned long long int u64;/**< used for unsigned 64bit */
#define BME280_64BITSUPPORT_PRESENT
#else
#warning Either the correct data type for signed 64 bit integer \
could not be found, or 64 bit integers are not supported in your environment.
#warning The API will only offer 32 bit pressure calculation.This will \
slightly impede accuracy(noise of ~1 pascal RMS will be added to output).
#warning If 64 bit integers are supported on your platform, \
please set s64 manually and "#define(BME280_64BITSUPPORT_PRESENT)" manually.
#endif

/*unsigned integer types*/
typedef	unsigned char u8;/**< used for unsigned 8bit */
typedef	unsigned short int u16;/**< used for unsigned 16bit */
typedef	unsigned long int u32;/**< used for unsigned 32bit */
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

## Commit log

2018-09-26 Added hardware files
    [pc_sensything_lite_v1.2.brd, pc_sensything_lite_v1.2.sch, pc_sensything_lite_v1.2.xls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]
2018-09-26 Updated Eagle schematic for v1.3 and PDF
    [pc_sensything_v1.3.brd, pc_sensything_v1.3.sch]
2018-11-15 Added and reorganized new hardware versions
    [pc_sensything_lite_v1.2.brd, pc_sensything_lite_v1.2.sch, pc_sensything_lite_v1.2.xls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]
2019-01-10 Update and rename experiments.md to Connecting to a sensor.md
2019-01-10 Update Connecting to a sensor.md
2019-01-22 Added Sensything BLE with Arduino
2019-02-17 added accelerometer code
2019-02-19 Added Sensything Arduino Ble

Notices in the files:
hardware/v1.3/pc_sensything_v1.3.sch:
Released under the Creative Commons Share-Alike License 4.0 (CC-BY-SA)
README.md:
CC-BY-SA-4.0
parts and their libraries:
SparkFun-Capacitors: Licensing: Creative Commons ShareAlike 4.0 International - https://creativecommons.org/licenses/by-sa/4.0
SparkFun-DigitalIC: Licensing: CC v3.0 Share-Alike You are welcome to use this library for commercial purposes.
